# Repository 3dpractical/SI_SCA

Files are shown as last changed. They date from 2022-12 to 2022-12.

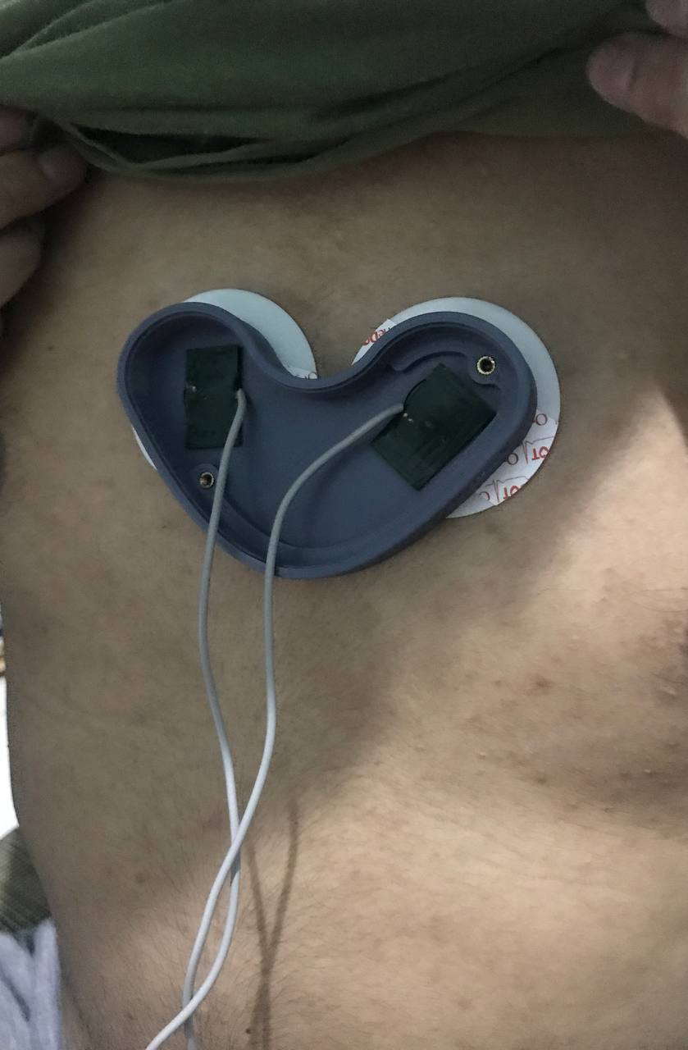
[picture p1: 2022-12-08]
Result Documentation/Pos-attempt01.jpg

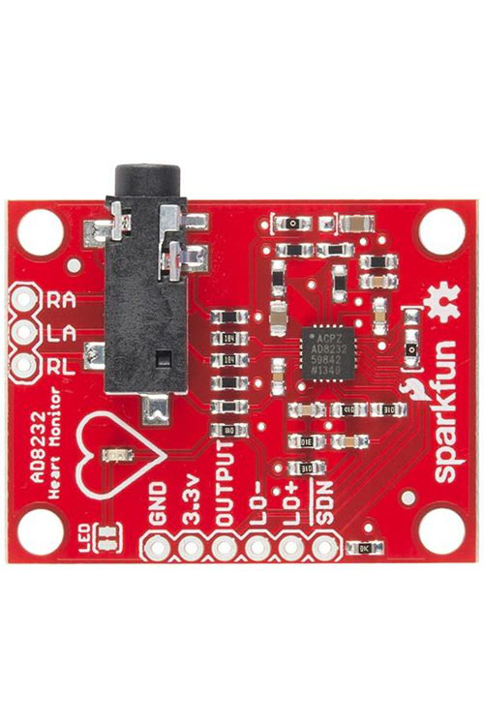
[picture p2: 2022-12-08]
Resources/REFERENCES/AD8232-ECG-Module.jpg

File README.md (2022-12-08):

# SI_SCA - Documentation





Si-SCA is a project to monitor heart rate and gyro status using Bluetooth Low Energy devices based on ESP32. This repository contain firmware for the devices to be installed.

## Library Used

 - [Adafruit MPU 6050](https://github.com/adafruit/Adafruit_MPU6050)
 - [NimBLE](https://github.com/h2zero/esp-nimble-cpp)
 - [RGB LED](https://github.com/FastLED/FastLED)
 - [FreeRTOS](https://docs.espressif.com/projects/esp-idf/en/latest/esp32/api-reference/system/freertos.html)
 - [TaskScheduler](https://github.com/arkhipenko/TaskScheduler)

## To-Do-List

- [X] ~~Establish Bluetooth Connection~~
- [X] ~~AD8232 HR Sensor Research~~
- [X] ~~Validate and Calibrate HR data~~
- [X] ~~MPU6050 get fixed Gyro data~~
- [X] ~~Validate and Calibrate Gyro data~~
- [X] ~~Get Battery Percentage Level~~
- [X] ~~Update BLE using NimBLE~~
- [X] ~~Add RGB Indicator~~
- [X] ~~Add Buzzer Indicator~~
- [X] ~~Configure Sleep Mode~~
- [X] ~~Import RTOS for better timing management~~
- [ ] Add AI for ECG signal detector

## License
This project is licensed under the MIT License - see the [LICENSE.md](LICENSE) file for details.

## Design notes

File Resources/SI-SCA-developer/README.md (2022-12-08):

# si_sca

A new Flutter project.

## Getting Started

This project is a starting point for a Flutter application.

A few resources to get you started if this is your first Flutter project:

- [Lab: Write your first Flutter app](https://flutter.dev/docs/get-started/codelab)
- [Cookbook: Useful Flutter samples](https://flutter.dev/docs/cookbook)

For help getting started with Flutter, view our
[online documentation](https://flutter.dev/docs), which offers tutorials,
samples, guidance on mobile development, and a full API reference.

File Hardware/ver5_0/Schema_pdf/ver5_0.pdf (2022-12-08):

# GND ¹k

Sheet: ABCD | 1 | 2 | 3 | 4 | 5 | 6 | ABCD 1 | 2 | 3 | 4 | 5 | 6

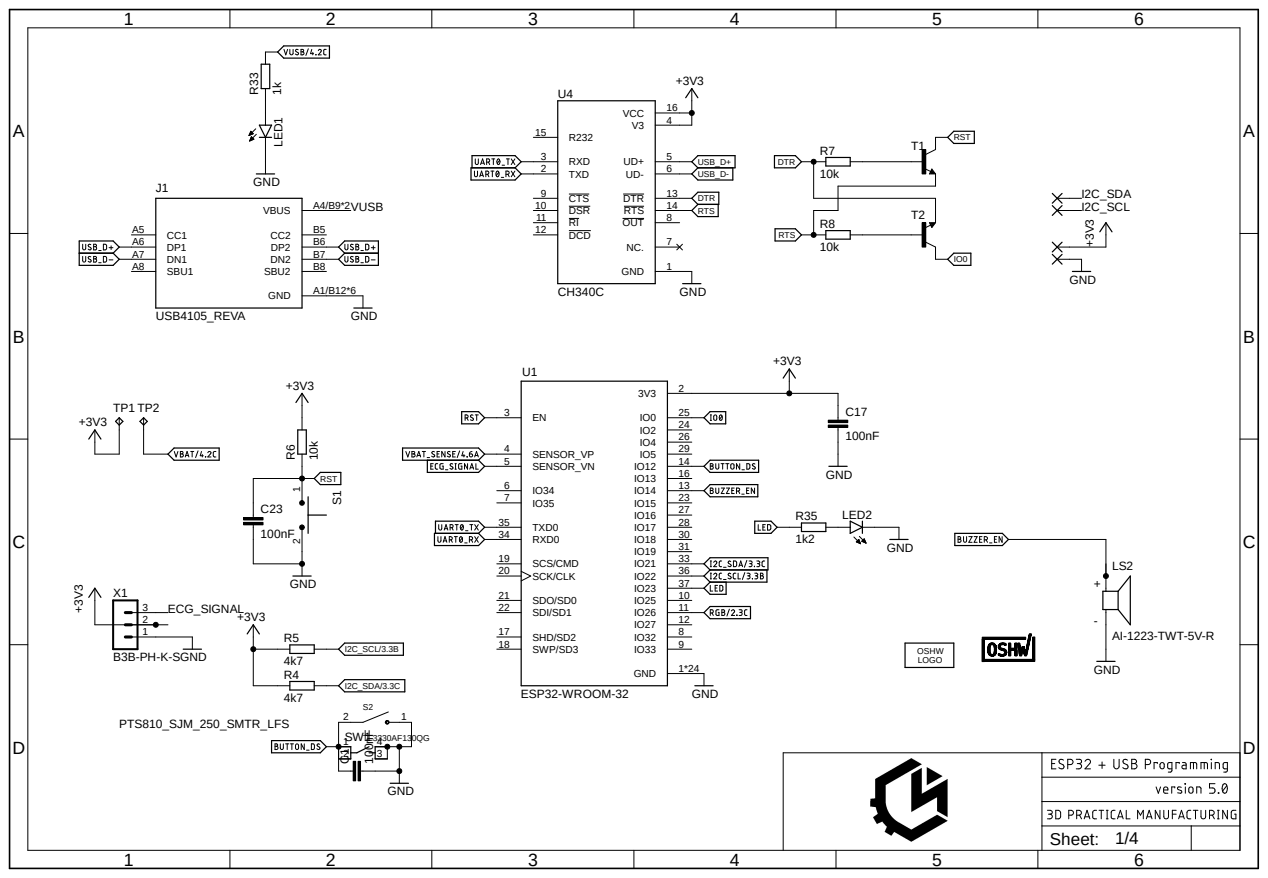
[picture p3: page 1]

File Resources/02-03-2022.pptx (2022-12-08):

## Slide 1

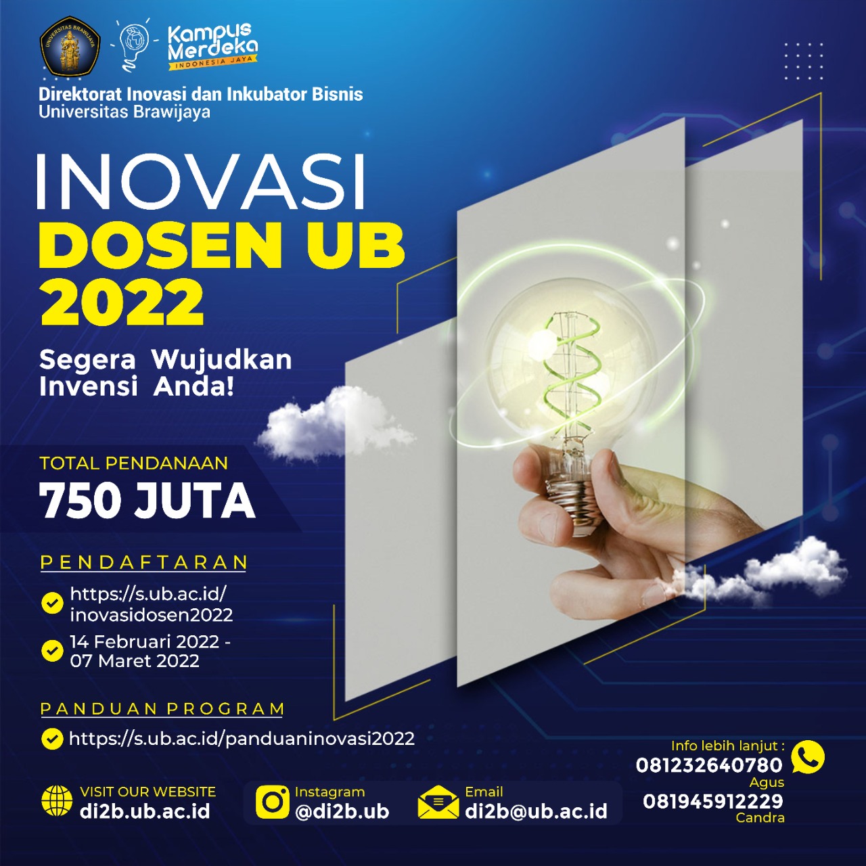
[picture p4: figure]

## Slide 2

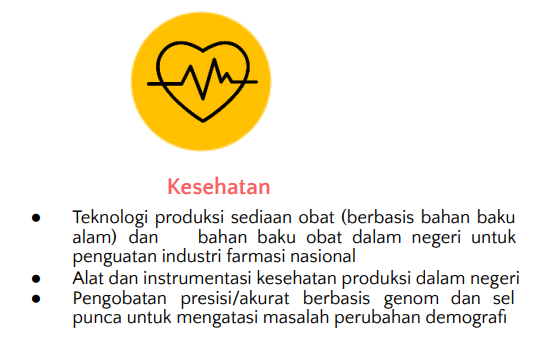
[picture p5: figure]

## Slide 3

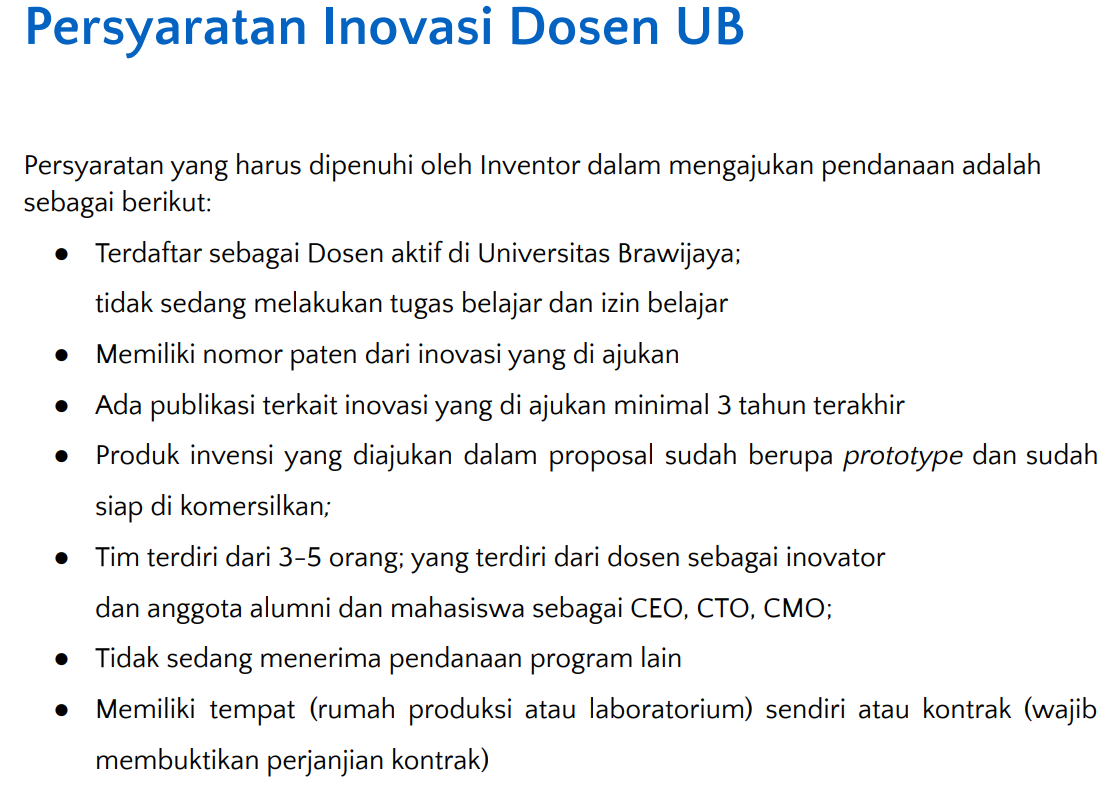
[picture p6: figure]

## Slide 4

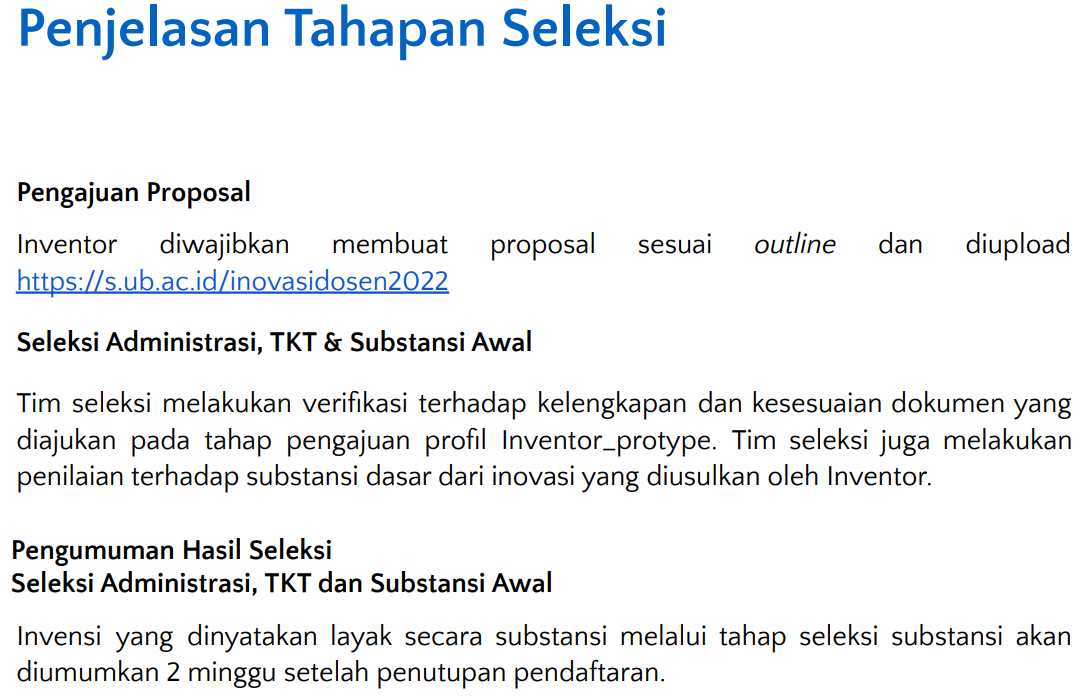
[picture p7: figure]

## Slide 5

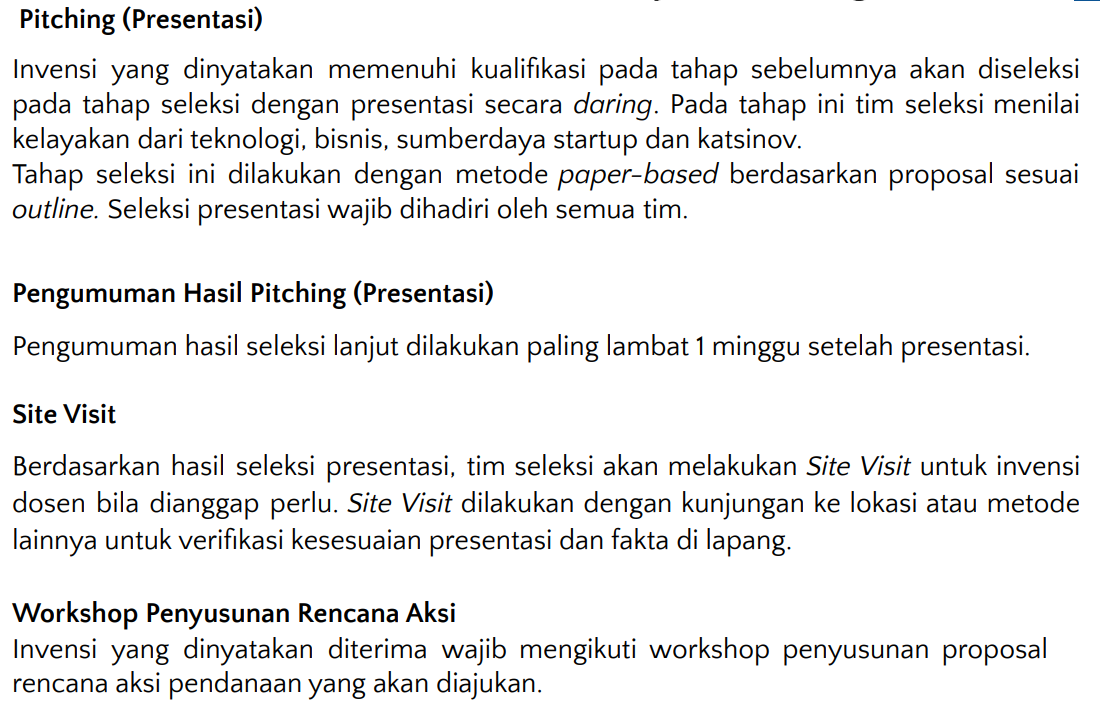
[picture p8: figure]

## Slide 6

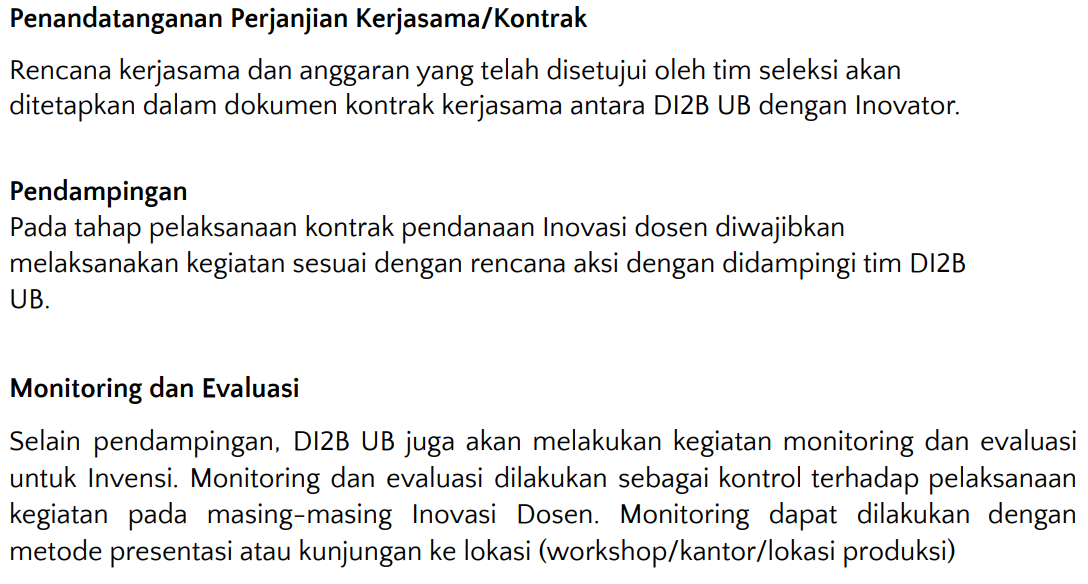
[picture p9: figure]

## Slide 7

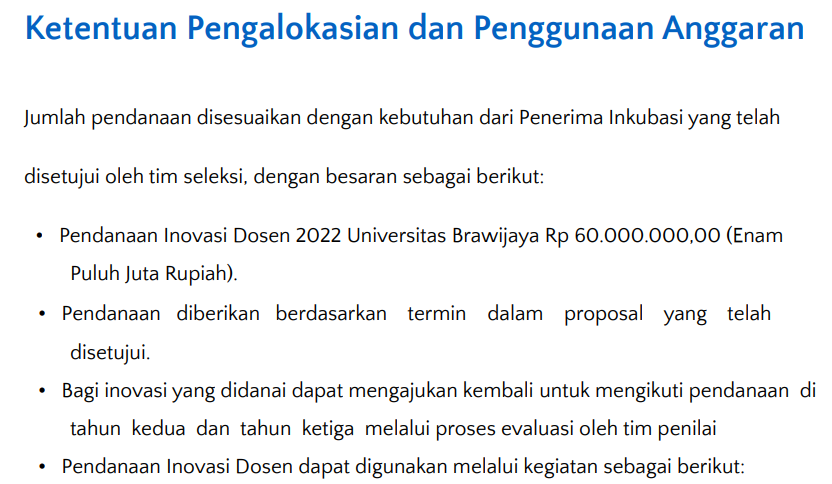
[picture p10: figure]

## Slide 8

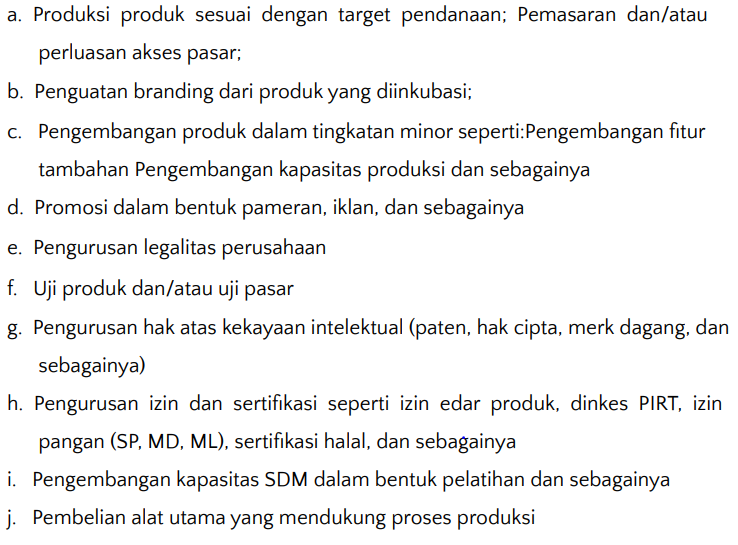
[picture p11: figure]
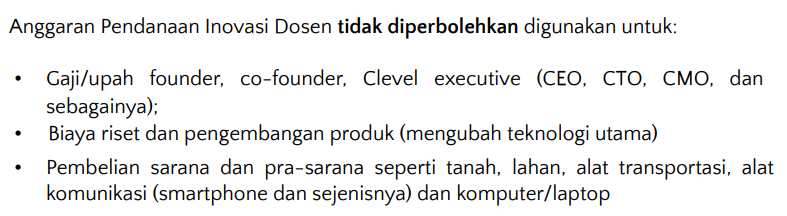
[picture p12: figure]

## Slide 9

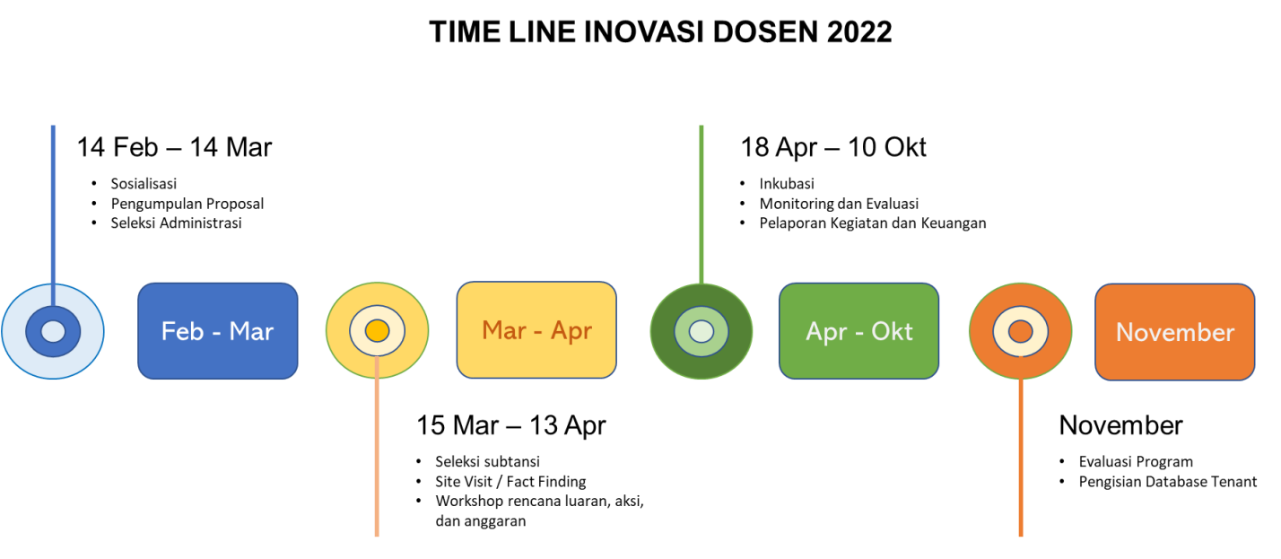
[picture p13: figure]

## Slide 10

Cover – Agil
Ringkasan Eksekutif – Agil
Lempeng – Agil
Profil Tim dan desain proposal – Agil
Bab 1 - Anita
Bab 2 – Chandra
Bab 3 - Chandra, Adrian, Rosa
Bab 4 - Rosa
Bab 5 - Chandra, Adrian, Rosa
Bab 6 - Chandra, Adrian, Rosa
Bab 7 - Chandra, Adrian, Rosa
Deadline 10 Maret + meeting lagi (jam menyusul)
13 Maret Dikumpul

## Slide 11

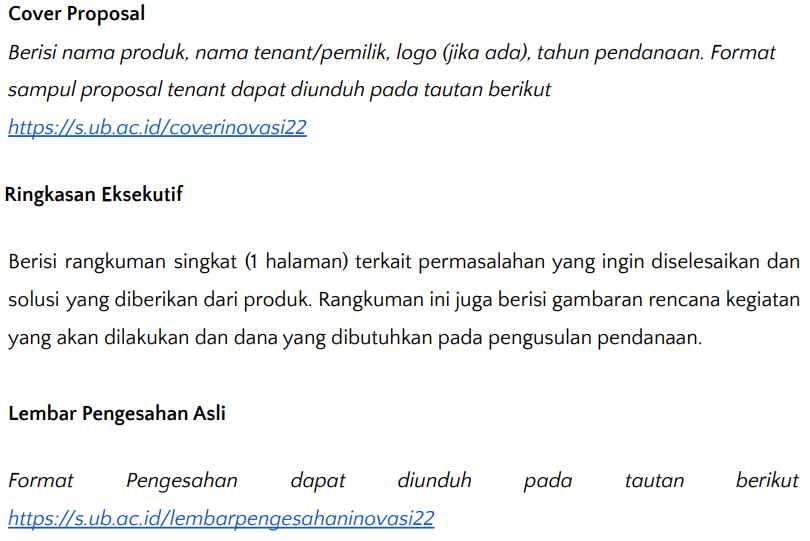
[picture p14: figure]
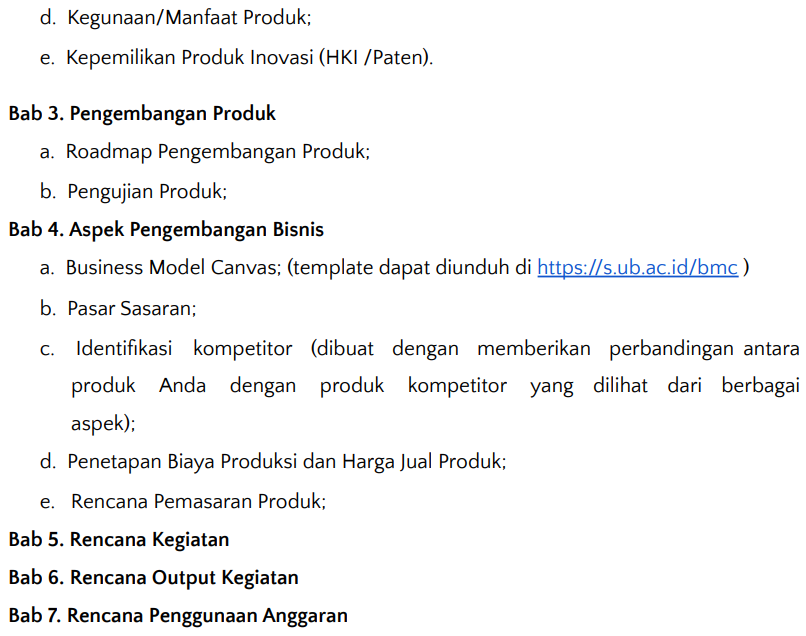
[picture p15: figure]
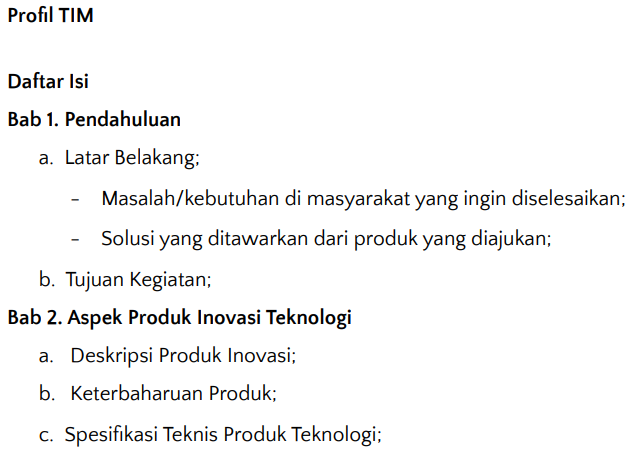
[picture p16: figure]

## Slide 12

Smart Wearable ECG EKG Monitor - (https://www.qardio.com/qardiocore-wearable-ecg-ekg-monitor-iphone/)QardioCore (https://www.qardio.com/qardiocore-wearable-ecg-ekg-monitor-iphone/)

HEALTHCARE PROFESSIONALS - (https://www.preventicesolutions.com/healthcare-professionals/)Preventice (https://www.preventicesolutions.com/healthcare-professionals/) Solutions (https://www.preventicesolutions.com/healthcare-professionals/)

EKG Anywhere, Anytime | (https://www.kardia.com/)AliveCor (https://www.kardia.com/) (kardia.com)

WISH for Health on Instagram: “Halo (https://www.instagram.com/p/CU9FhnEBYKi/?utm_source=ig_web_copy_link)teman-teman (https://www.instagram.com/p/CU9FhnEBYKi/?utm_source=ig_web_copy_link) (https://www.instagram.com/p/CU9FhnEBYKi/?utm_source=ig_web_copy_link)Imersif (https://www.instagram.com/p/CU9FhnEBYKi/?utm_source=ig_web_copy_link) Mari (https://www.instagram.com/p/CU9FhnEBYKi/?utm_source=ig_web_copy_link)kita (https://www.instagram.com/p/CU9FhnEBYKi/?utm_source=ig_web_copy_link) (https://www.instagram.com/p/CU9FhnEBYKi/?utm_source=ig_web_copy_link)sambut (https://www.instagram.com/p/CU9FhnEBYKi/?utm_source=ig_web_copy_link) (https://www.instagram.com/p/CU9FhnEBYKi/?utm_source=ig_web_copy_link)awal (https://www.instagram.com/p/CU9FhnEBYKi/?utm_source=ig_web_copy_link) (https://www.instagram.com/p/CU9FhnEBYKi/?utm_source=ig_web_copy_link)bulan (https://www.instagram.com/p/CU9FhnEBYKi/?utm_source=ig_web_copy_link) (https://www.instagram.com/p/CU9FhnEBYKi/?utm_source=ig_web_copy_link)dengan (https://www.instagram.com/p/CU9FhnEBYKi/?utm_source=ig_web_copy_link) quiz (https://www.instagram.com/p/CU9FhnEBYKi/?utm_source=ig_web_copy_link)menarik (https://www.instagram.com/p/CU9FhnEBYKi/?utm_source=ig_web_copy_link) (https://www.instagram.com/p/CU9FhnEBYKi/?utm_source=ig_web_copy_link)dari (https://www.instagram.com/p/CU9FhnEBYKi/?utm_source=ig_web_copy_link) WISH Buat kalian followers (https://www.instagram.com/p/CU9FhnEBYKi/?utm_source=ig_web_copy_link)kita (https://www.instagram.com/p/CU9FhnEBYKi/?utm_source=ig_web_copy_link) (https://www.instagram.com/p/CU9FhnEBYKi/?utm_source=ig_web_copy_link)pasti (https://www.instagram.com/p/CU9FhnEBYKi/?utm_source=ig_web_copy_link) tau (https://www.instagram.com/p/CU9FhnEBYKi/?utm_source=ig_web_copy_link)apa (https://www.instagram.com/p/CU9FhnEBYKi/?utm_source=ig_web_copy_link) (https://www.instagram.com/p/CU9FhnEBYKi/?utm_source=ig_web_copy_link)saja (https://www.instagram.com/p/CU9FhnEBYKi/?utm_source=ig_web_copy_link) (https://www.instagram.com/p/CU9FhnEBYKi/?utm_source=ig_web_copy_link)fitur (https://www.instagram.com/p/CU9FhnEBYKi/?utm_source=ig_web_copy_link) yang…” (https://www.instagram.com/p/CU9FhnEBYKi/?utm_source=ig_web_copy_link)

Spire Health | Remote Patient Monitoring (https://www.spirehealth.com/)

Aktiia (https://aktiia.com/uk/) - Your Home Blood Pressure Monitoring Solution (https://aktiia.com/uk/)

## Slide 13

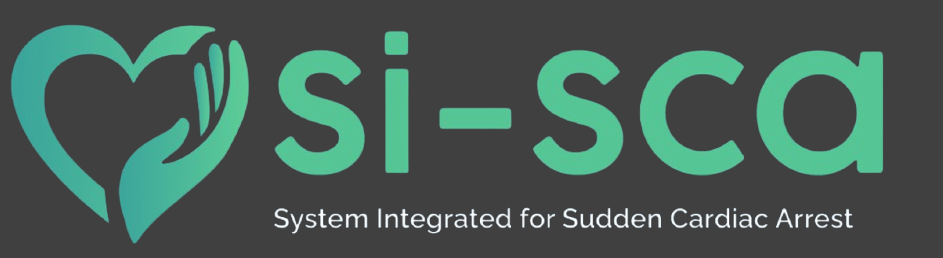
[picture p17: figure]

2.0 ?

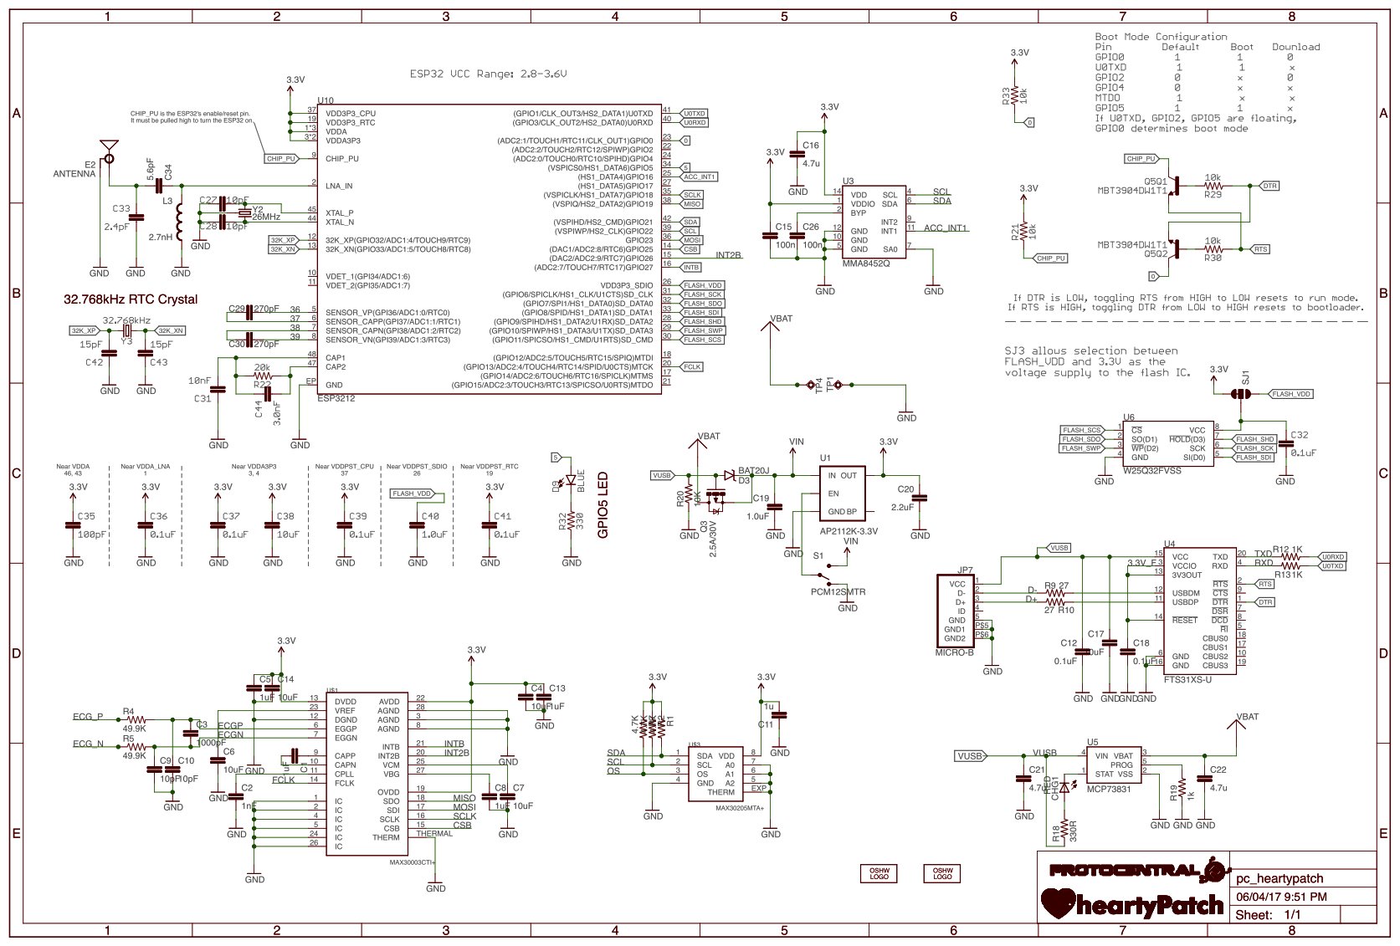
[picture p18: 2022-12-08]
Resources/Protocentral PCB Schematic.jpg

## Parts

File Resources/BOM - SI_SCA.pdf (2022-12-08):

No. | Item | Qty | Price Total
1 | Hardware Development | 1 | Rp10,000,000.00
2 | Programming | 1 | Rp4,000,000.00
3 | BLE Configuration | 1 | Rp1,500,000.00
4 | Backend App | 1 | Rp6,000,000.00
5 | Frontend App | 1 | Rp5,000,000.00
6 | AI Detection Method | 1 | Rp7,000,000.00
TOTAL | | | Rp33,500,000.00

Bill Of Material
SISCAA - EKG BPM Monitoring

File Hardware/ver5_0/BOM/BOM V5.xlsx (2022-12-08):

Qty | Value | Device | Package | Parts | Description | AVAILABILITY | DESCRIPTION | MF | MP | PACKAGE | POPULARITY | PRICE | PURCHASE-URL | SPICEPREFIX | TP_SIGNAL_NAME
1 |  | CERT-SMALL | CERT-SMALL-SILK | U$10
4 |  | LEDCHIP-LED0603 | CHIP-LED0603 | LED1, LED2, LED3, LED4 | LED |  |  |  |  |  | 26
2 |  | MMBT4401LT1-NPN-SOT23-BEC | SOT23-BEC | T1, T2 | NPN Transistror
1 | 100 | R-EU_R0603 | R0603 | R13 | RESISTOR, European symbol |  |  |  |  |  | 70 |  |  | R
1 | 100k | R-EU_R0603 | R0603 | R15 | RESISTOR, European symbol |  |  |  |  |  | 70 |  |  | R
8 | 100nF | C-EUC0603 | C0603 | C1, C4, C17, C23, C24, C29, C31, C32 | CAPACITOR, European symbol |  |  |  |  |  | 73 |  |  | C
5 | 10k | R-EU_R0603 | R0603 | R6, R7, R8, R9, R16 | RESISTOR, European symbol |  |  |  |  |  | 70 |  |  | R
1 | 10uF | C-EUC0603 | C0603 | C5 | CAPACITOR, European symbol |  |  |  |  |  | 73 |  |  | C
1 | 1N5819HW-7 | 1N5819HW-7 | SOD3715X145N | D2 | 1N5819HW Series 40 V 1 A Surface Mount Schottky Barrier Rectifier - SOD-123 Check availability | In Stock | Diode Schottky 40 V 1A Surface Mount SOD-123 | Diodes Inc. | 1N5819HW-7 | SOD-123 Fairchild Semiconductor |  | None | https://pricing.snapeda.com/search/part/1N5819HW-7/?ref=eda
4 | 1k | R-EU_R0603 | R0603 | R1, R2, R12, R33 | RESISTOR, European symbol |  |  |  |  |  | 70 |  |  | R
2 | 1k2 | R-EU_R0603 | R0603 | R3, R35 | RESISTOR, European symbol |  |  |  |  |  | 70 |  |  | R
2 | 1uF | C-EUC0603 | C0603 | C6, C7 | CAPACITOR, European symbol |  |  |  |  |  | 73 |  |  | C
1 | 220pF | C-EUC0603 | C0603 | C30 | CAPACITOR, European symbol |  |  |  |  |  | 73 |  |  | C
1 | 27k | R-EU_R0603 | R0603 | R14 | RESISTOR, European symbol |  |  |  |  |  | 70 |  |  | R
4 | 4k7 | R-EU_R0603 | R0603 | R4, R5, R10, R11 | RESISTOR, European symbol |  |  |  |  |  | 70 |  |  | R
1 | AI-1223-TWT-5V-R | AI-1223-TWT-5V-R | XDCR_AI-1223-TWT-5V-R | LS2 | Check availability | In Stock | ELECTRO MECHANICAL AUDIO INDICATOR | PUI Audio, | AI-1223-TWT-5V-R | 2225 PUI Audio |  | None | https://pricing.snapeda.com/search/part/AI-1223-TWT-5V-R/?ref=eda
1 | B3B-PH-K-S | B3B-PH-K-S | B3B-PH-K-S | X1 | JST PH series header 2.00mm pitch disconnectable crimp style connectors, vertical (side entry type), 3 pins
1 | CH340C | CH340C | SOIC127P600X180-16N | U4 | USB to serial chip CH340 Check availability | Not in stock | USB to serial chip CH340 | WCH | CH340C | None |  | None
1 | DW01A | DW01A | SOT23-6 | IC2 | Check availability | Not in stock | One Cell Lithium-ion/Polymer Battery Protection IC | Fortune Semiconductor | DW01A | SOT-23-6 Fortune Semiconductor |  | None
1 | ESP32-WROOM-32 | ESP32-WROOM-32 | MODULE_ESP32-WROOM-32 | U1 | Bluetooth, WiFi Transceiver Module 2.4GHz ~ 2.5GHz Surface Mount | Unavailable | Bluetooth, WiFi 802.11b/g/n, Bluetooth v4.2 +EDR, Class 1, 2 and 3 Transceiver Module 2.4GHz ~ 2.5GHz Antenna Not Included, U.FL Surface Mount | Espressif Systems | ESP32-WROOM-32 | Module Espressif Systems |  | None
1 | FS8205A | FS8205A | SOP65P640X120-8N | Q3 | N/A Check availability | Not in stock |  | Fortune Semiconductor | FS8205A | Package |  | None
1 | MCP1700T-3302E/TT | MCP1700T-3302E/TT | SOT95P237X112-3N | U$2 | Check availability | In Stock | Linear Voltage Regulator IC Positive Fixed 1 Output 250mA SOT-23-3 | Microchip | MCP1700T-3302E/TT | SOT-23 Microchip |  | None | https://pricing.snapeda.com/search/part/MCP1700T-3302E/TT/?ref=eda
1 | MPU-6050 | MPU-6050 | QFN50P400X400X95-24N | U11 | MPU-6050 Six-Axis (Gyro + Accelerometer) MEMS MotionTracking™ Devices Check availability | In Stock | MPU-6050 series Accelerometer, Gyroscope, 3 Axis Sensor Evaluation Board | TDK InvenSense | MPU-6050 | QFN-24 InvenSense |  | None | https://pricing.snapeda.com/search/part/MPU-6050/?ref=eda
1 | OSHW_LOGO_FILLX0200-NT | OSHW_LOGO_FILLX0200-NT | OSHW_FILLX200_NOTEXT | LOGO2
1 | PTS810_SJM_250_SMTR_LFS | PTS810_SJM_250_SMTR_LFS | SW_PTS810_SJM_250_SMTR_LFS | SW1 | Switch Tactile Spst-No 0.05a 16v Check prices | In Stock | Tactile Switch SPST-NO Top Actuated Surface Mount | C&K | PTS810 SJM 250 SMTR LFS | None |  | None | https://pricing.snapeda.com/search/part/PTS810 SJM 250 SMTR LFS/?ref=eda
1 | TL1015AF160QG | TL1015AF160QG | SW_TL1015AF160QG | S1 | Tactile Switch SPST-NO Top Actuated Surface Mount Check prices | In Stock | Tactile Switch SPST-NO Top Actuated Surface Mount | E-Switch | TL1015AF160QG | SOIC-14 E-Switch |  | None | https://pricing.snapeda.com/search/part/TL1015AF160QG/?ref=eda
1 | TL3330AF130QG | TL3330AF130QG | SW_TL3330AF130QG | S2 | Check availability | In Stock | Tactile Switch SPST-NO Side Actuated Surface Mount, Right Angle | E-Switch | TL3330AF130QG | None |  | None | https://pricing.snapeda.com/search/part/TL3330AF130QG/?ref=eda
1 | TP4056 | TP4056 | SOP127P600X175-9N | U2 | Complete single cell Li-Ion battery with a constant current / constant voltage linear charger Check availability | Not in stock | Complete single cell Li-Ion battery with a constant current / constant voltage linear charger | NanJing Top Power ASIC Corp. | TP4056 | None |  | None
2 | TPB1,27 | TPB1,27 | B1,27 | TP1, TP2 | Test pad |  |  |  |  |  | 19
1 | TRANSISTOR-FET_DMP2004K | TRANSISTOR-FET_DMP2004K | TRANSISTOR-FET_SOT23 | Q4 | P-Channel Enhancement MOSFET
1 | USB4105_REVA | USB4105_REVA | GCT_USB4105_REVA | J1 | USB Type C Receptacle for USB 2.0 | Unavailable | USB-C (USB TYPE-C) USB 2.0 Receptacle Connector 24 (16+8 Dummy) Position Surface Mount, Right Angle | Through Hole | Global Connector Technology | USB4105 | Package |  | None
6 | WIREPADSMD1,27-254 | WIREPADSMD1,27-254 | SMD1,27-2,54 | PAD1, PAD2, PAD3, PAD4, VBAT+, VBAT- | Wire PAD connect wire on PCB |  |  |  |  |  | 11
1 | WS2812B-B | WS2812B-B | LED_WS2812B-B | U5 | Intelligent control LED integrated light source Check availability | Not in stock | Intelligent control LED integrated light source | Worldsemi | WS2812B-B | Package |  | None

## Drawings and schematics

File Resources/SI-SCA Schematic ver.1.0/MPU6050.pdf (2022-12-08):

A

A

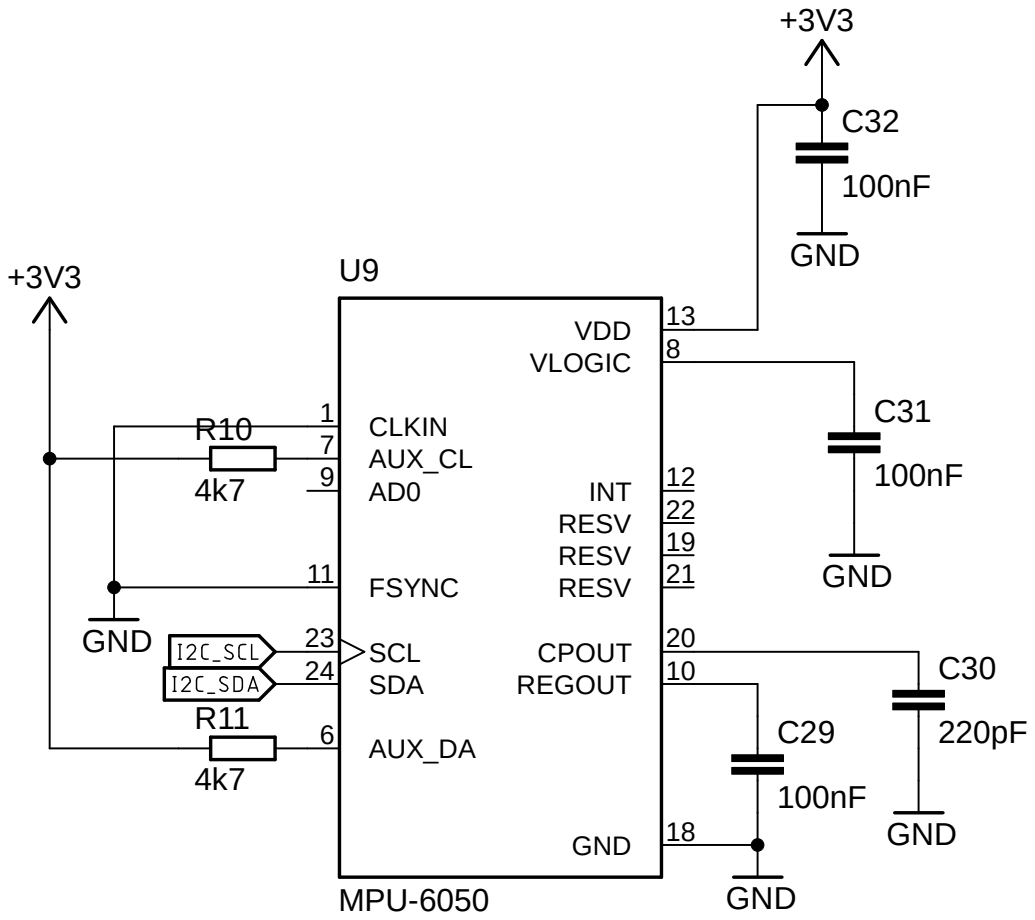
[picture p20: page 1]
GND; MPU-6050; GND +3V3; C31 CLKIN 1 AUX_CL 7 AD0 9; FSYNC 11; SCL 23; AUX_DA 6; SDA 24; INT; REGOUT; 10 CPOUT; RESV; VLOGIC; 8 VDD; Sheet:

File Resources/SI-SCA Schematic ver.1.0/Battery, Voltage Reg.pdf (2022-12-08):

A

A

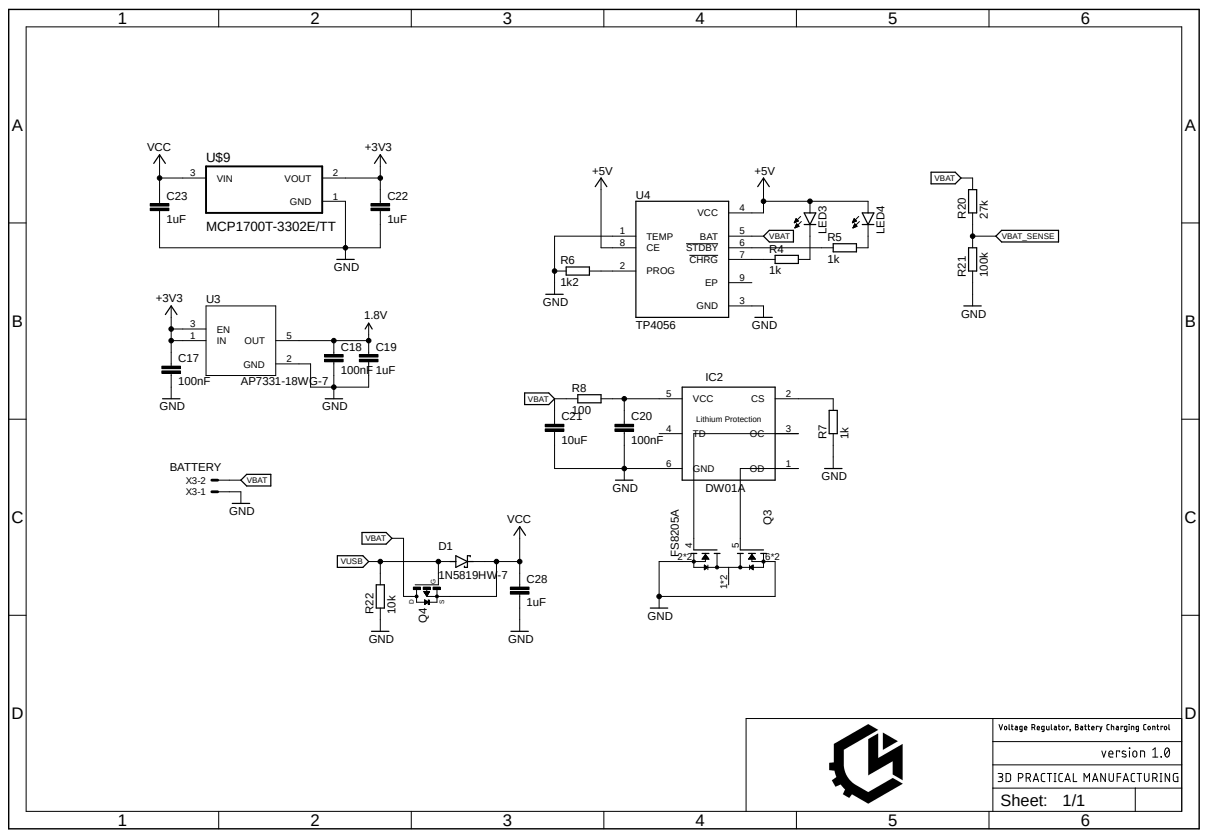
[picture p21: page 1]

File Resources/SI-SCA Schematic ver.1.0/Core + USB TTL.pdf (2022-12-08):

BUZZER | Sheet: ABCD | 1 | 2 | 3 | 4 | 5 | 6 | ABCD 1 | 2 | 3 | 4 | 5 | 6

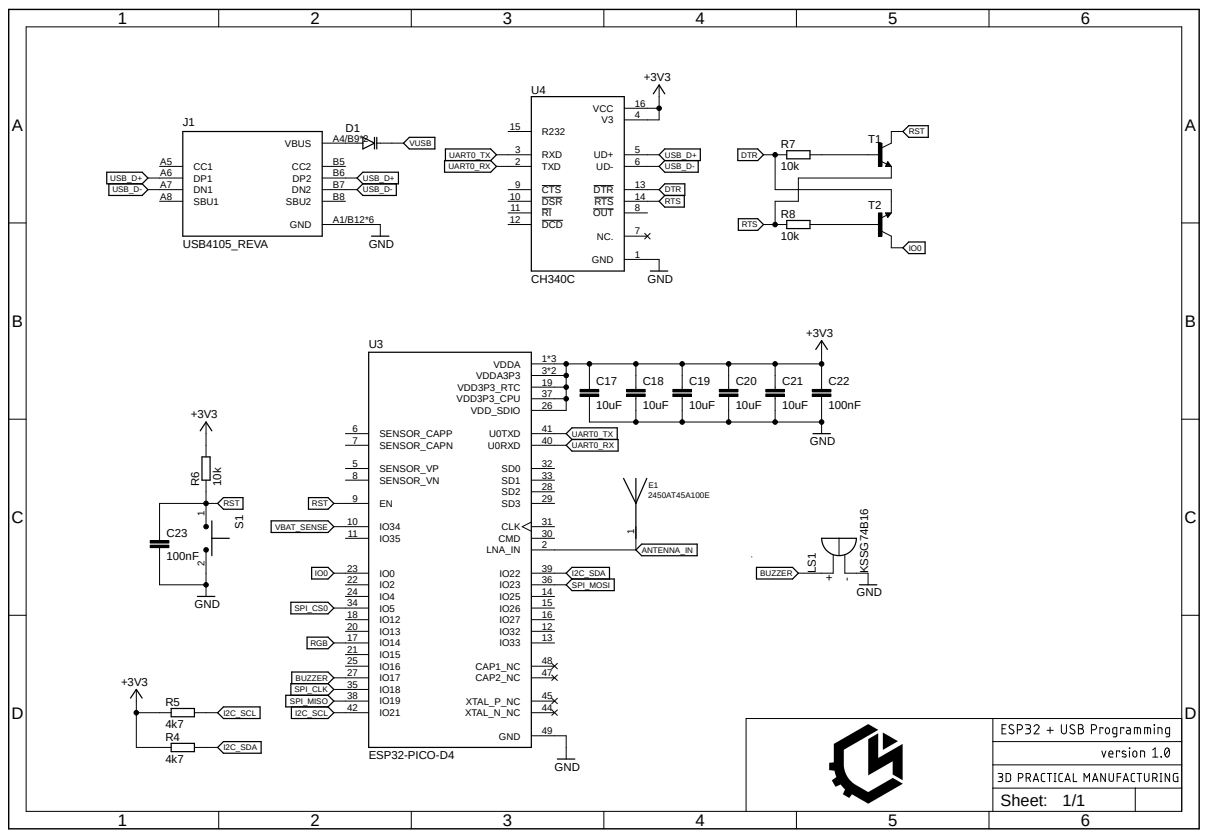
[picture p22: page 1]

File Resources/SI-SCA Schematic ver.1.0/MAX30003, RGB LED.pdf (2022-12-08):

A

A

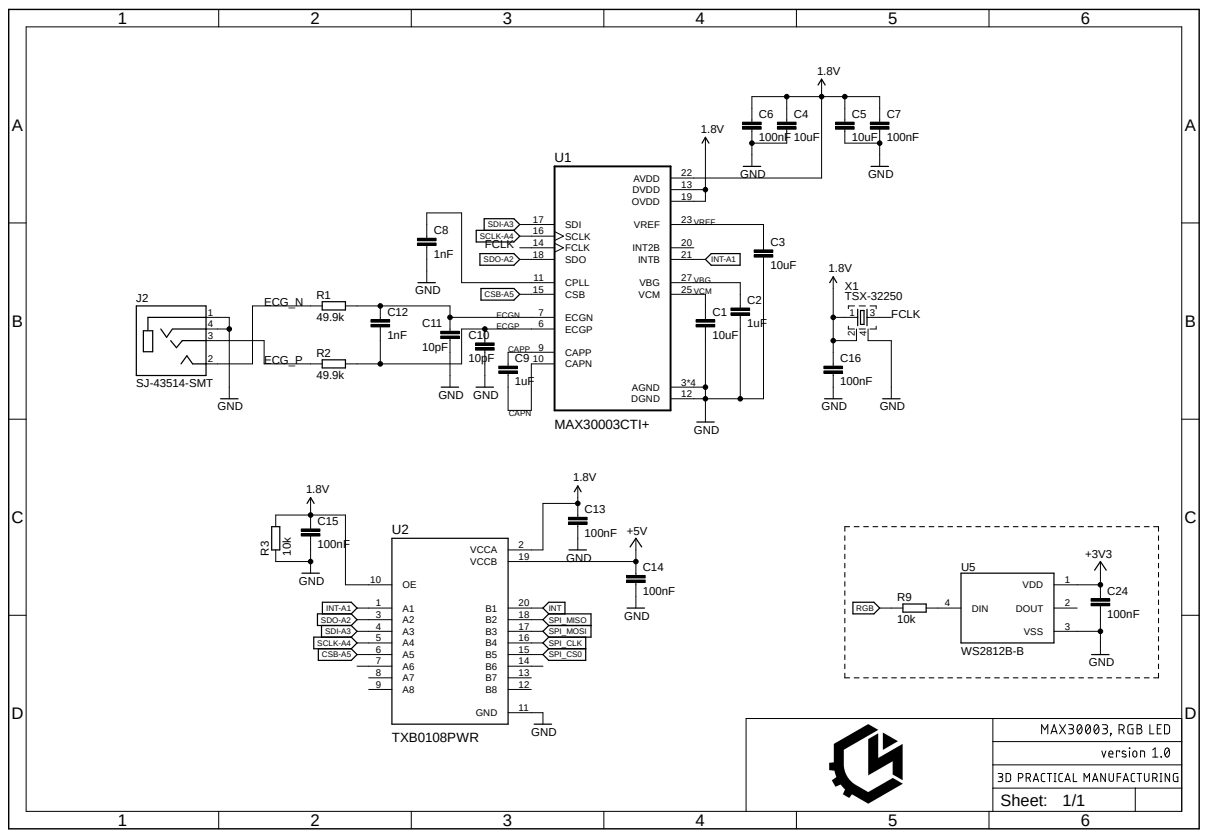
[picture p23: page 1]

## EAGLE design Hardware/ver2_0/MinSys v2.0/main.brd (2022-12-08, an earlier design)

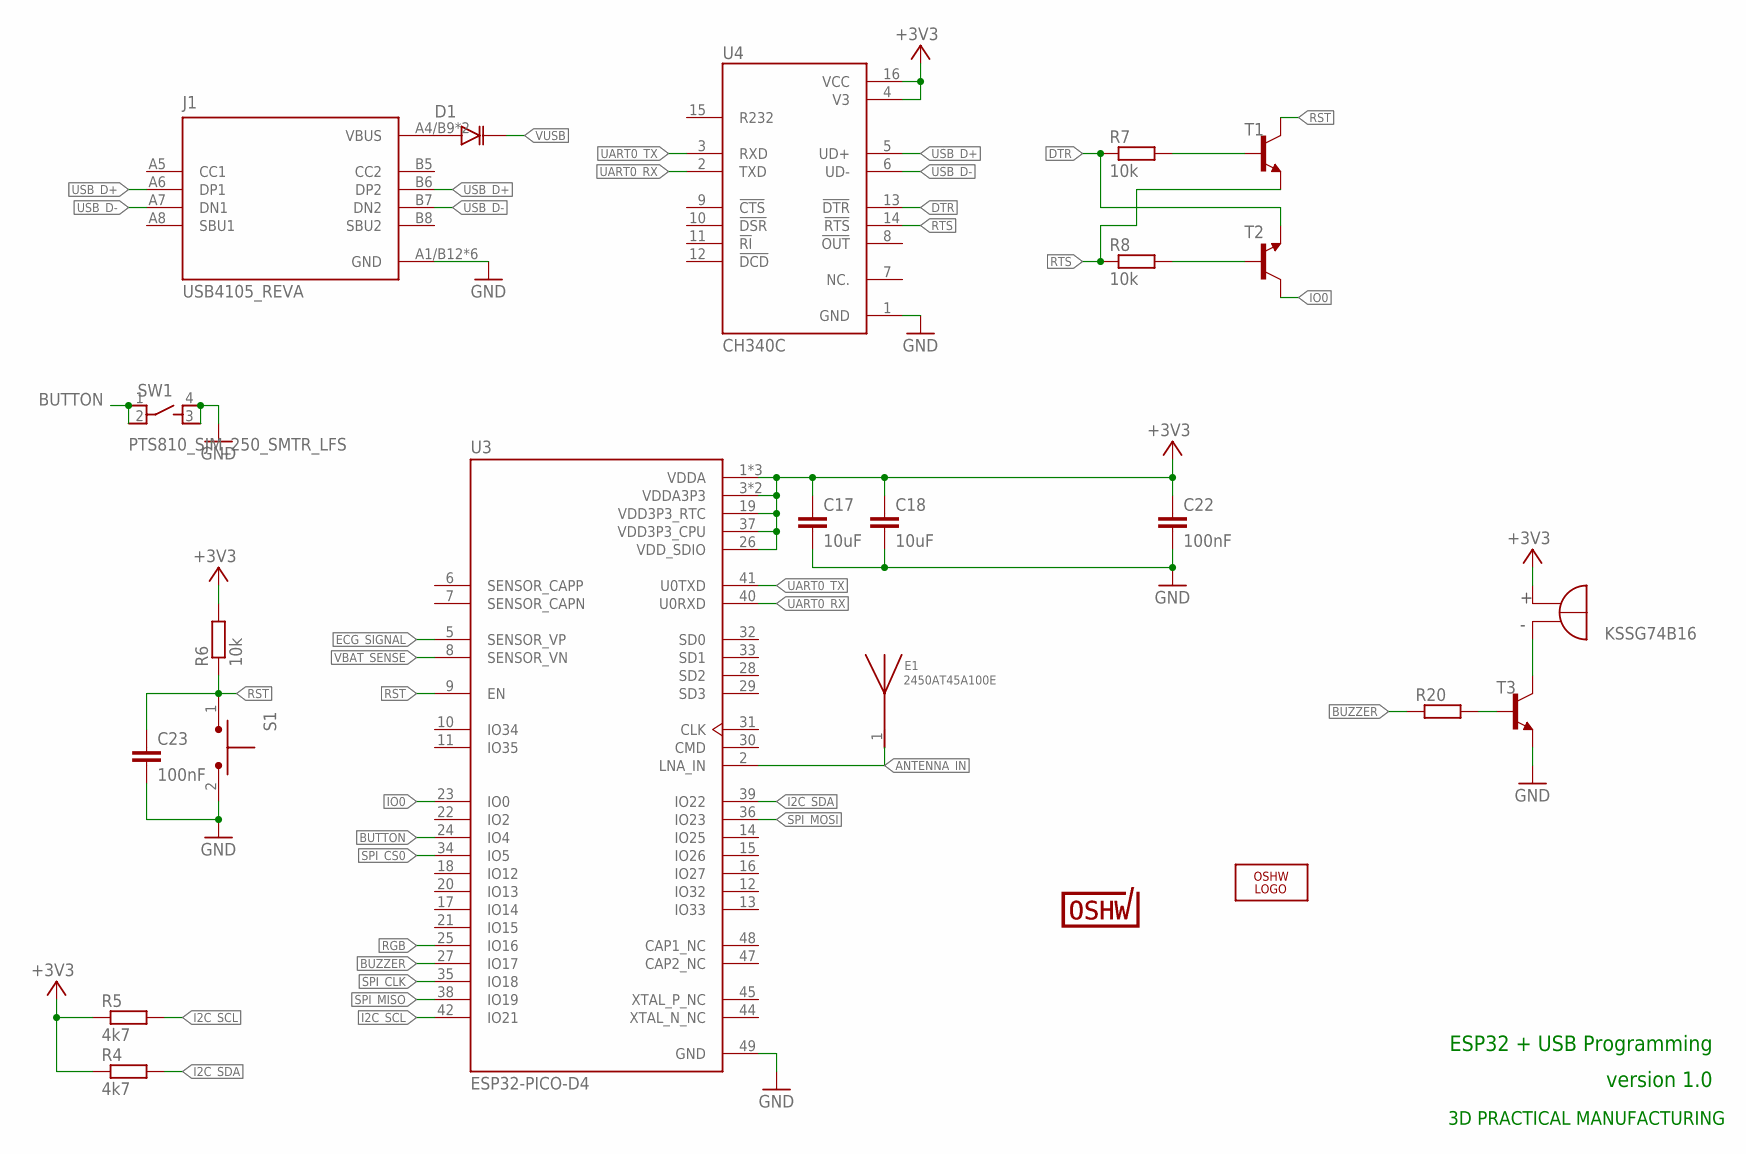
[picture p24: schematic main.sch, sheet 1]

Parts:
C17, C18: 10uF; C0603
C22, C23: 100nF; C0603
D1: ZMV829BTA; SOD2512X116N
E1: 2450AT45A100E; ANT_2450AT45A100E
J1: USB4105_REVA; GCT_USB4105_REVA
LOGO2: OSHW_LOGO_FILLX0200-NT; OSHW_FILLX200_NOTEXT
LS1: KSSG74B16; XDCR_KSSG74B16
R4, R5: 4k7; R0603
R6, R7, R8: 10k; R0603
R20: R-EU_R0603; R0603
S1: TL1015AF160QG; SW_TL1015AF160QG
SW1: PTS810_SJM_250_SMTR_LFS; SW_PTS810_SJM_250_SMTR_LFS
T1, T2, T3: MMBT4401LT1-NPN-SOT23-BEC; SOT23-BEC
U3: ESP32-PICO-D4; PQFN50P700X700X104-49N
U4: CH340C; SOIC127P600X180-16N
U$10: CERT-SMALL; CERT-SMALL-SILK

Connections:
+3V3: C17.1, C18.1, C22.1, LS1.P (POS), R4.1, R5.1, R6.2, U3.1 (VDDA), U3.3 (VDDA3P3), U3.4 (VDDA3P3), U3.19 (VDD3P3_RTC), U3.26 (VDD_SDIO), U3.37 (VDD3P3_CPU), U3.43 (VDDA), U3.46 (VDDA), U4.4 (V3), U4.16 (VCC); also elsewhere on the board
ANTENNA_IN: E1.1, U3.2 (LNA_IN)
BUTTON: SW1.1, SW1.2, U3.24 (IO4)
BUZZER: R20.1, U3.27 (IO17)
DTR: R7.1, T2.E, U4.13 (!DTR)
ECG_SIGNAL: U3.5 (SENSOR_VP); also elsewhere on the board
GND: C17.2, C18.2, C22.2, C23.2, J1.A1/B12 (GND), J1.B1/A12 (GND), J1.G1 (GND), J1.G2 (GND), J1.G3 (GND), J1.G4 (GND), S1.2, SW1.3, SW1.4, T3.E, U3.49 (GND), U4.1 (GND); also elsewhere on the board
I2C_SCL: R5.2, U3.42 (IO21); also elsewhere on the board
I2C_SDA: R4.2, U3.39 (IO22); also elsewhere on the board
IO0: T2.C, U3.23 (IO0)
unnamed: R7.2, T1.B
unnamed: R8.2, T2.B
unnamed: R20.2, T3.B
unnamed: D1.A, J1.A4/B9 (VBUS), J1.B4/A9 (VBUS)
unnamed: LS1.N (NEG), T3.C
RGB: U3.25 (IO16); also elsewhere on the board
RST: C23.1, R6.1, S1.1, T1.C, U3.9 (EN)
RTS: R8.1, T1.E, U4.14 (!RTS)
SPI_CLK: U3.35 (IO18)
SPI_CS0: U3.34 (IO5)
SPI_MISO: U3.38 (IO19)
SPI_MOSI: U3.36 (IO23)
UART0_RX: U3.40 (U0RXD), U4.2 (TXD)
UART0_TX: U3.41 (U0TXD), U4.3 (RXD)
USB_D+: J1.A6 (DP1), J1.B6 (DP2), U4.5 (UD+)
USB_D-: J1.A7 (DN1), J1.B7 (DN2), U4.6 (UD-)
VBAT_SENSE: U3.8 (SENSOR_VN); also elsewhere on the board
VUSB: D1.K; also elsewhere on the board

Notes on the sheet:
ESP32 + USB Programming
3D PRACTICAL MANUFACTURING
version 1.0

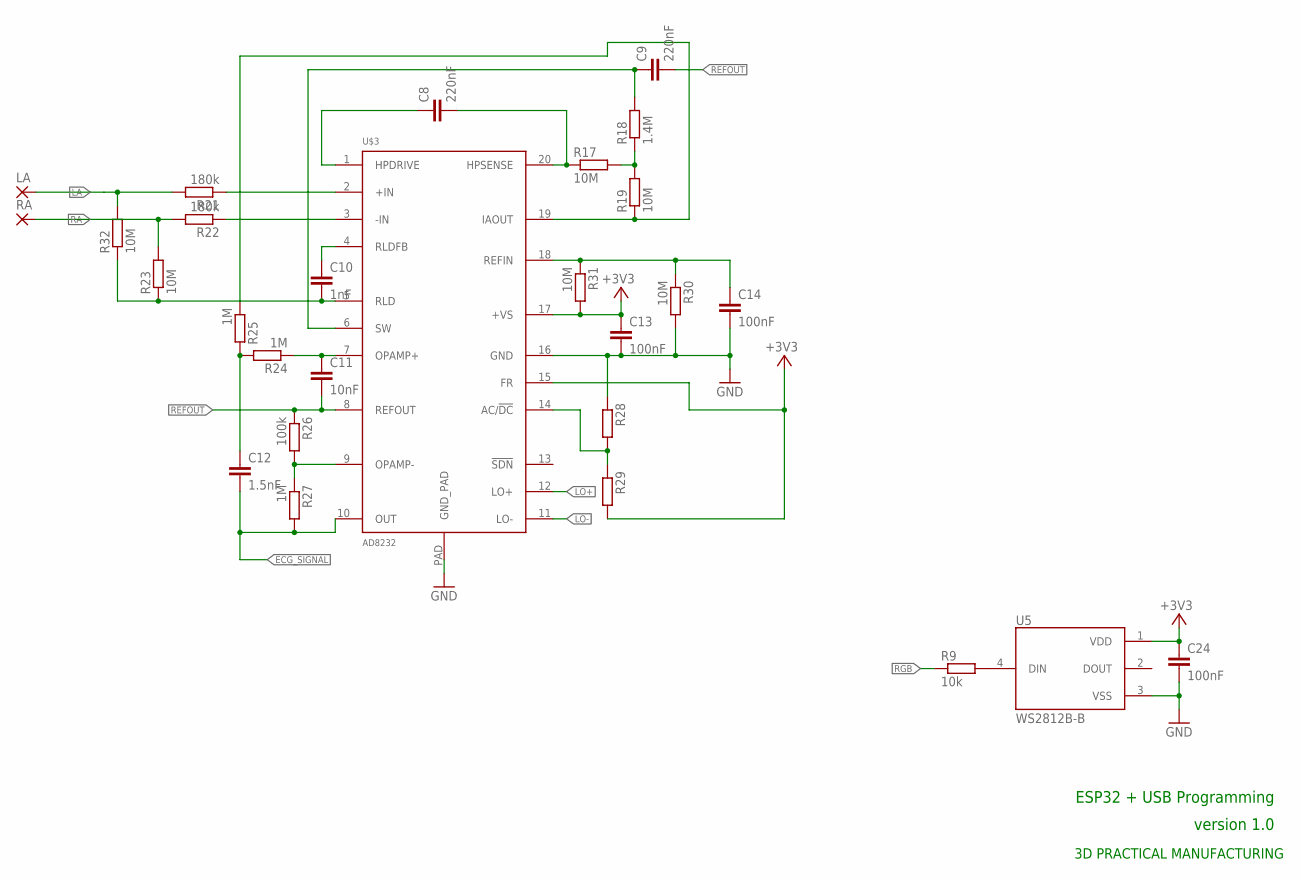
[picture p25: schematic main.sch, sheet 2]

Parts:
C8, C9: 220nF; C0603
C10: 1nF; C0603
C11: 10nF; C0603
C12: 1.5nF; C0603
C13, C14, C24: 100nF; C0603
LA: SMD2; SMD1,27-2,54
R9: 10k; R0603
R17, R19, R23, R30, R31, R32: 10M; R0603
R18: 1.4M; R0603
R21, R22: 180k; R0603
R24, R25, R27: 1M; R0603
R26: 100k; R0603
R28, R29: R-EU_R0603; R0603
RA: SMD2; SMD1,27-2,54
U5: WS2812B-B; LED_WS2812B-B
U$3: AD8232; LFCSP_20

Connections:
+3V3: C13.1, C24.1, R29.2, R31.2, U5.1 (VDD), U$3.15 (FR), U$3.17 (+VS); also elsewhere on the board
ECG_SIGNAL: C12.2, R27.2, U$3.10 (OUT); also elsewhere on the board
GND: C13.2, C14.2, C24.2, R28.1, R30.2, U5.3 (VSS), U$3.16 (GND), U$3.PAD (GND_PAD); also elsewhere on the board
LA: LA.1, R21.2, R32.2
LO+: U$3.12 (LO+)
LO-: U$3.11 (LO-)
unnamed: R9.2, U5.4 (DIN)
unnamed: C8.2, R17.1, U$3.20 (HPSENSE)
unnamed: C8.1, U$3.1 (HPDRIVE)
unnamed: R19.1, R25.1, U$3.19 (IAOUT)
unnamed: R17.2, R18.1, R19.2
unnamed: C9.1, R18.2, U$3.6 (SW)
unnamed: C12.1, R24.2, R25.2
unnamed: R21.1, U$3.2 (+IN)
unnamed: R22.1, U$3.3 (-IN)
unnamed: C10.1, U$3.4 (RLDFB)
unnamed: C10.2, R23.1, R32.1, U$3.5 (RLD)
unnamed: C11.1, R24.1, U$3.7 (OPAMP+)
unnamed: R26.2, R27.1, U$3.9 (OPAMP-)
unnamed: R28.2, R29.1, U$3.14 (AC/!DC)
unnamed: C14.1, R30.1, R31.1, U$3.18 (REFIN)
RA: R22.2, R23.2, RA.1
REFOUT: C9.2, C11.2, R26.1, U$3.8 (REFOUT)
RGB: R9.1; also elsewhere on the board

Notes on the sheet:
ESP32 + USB Programming
3D PRACTICAL MANUFACTURING
version 1.0

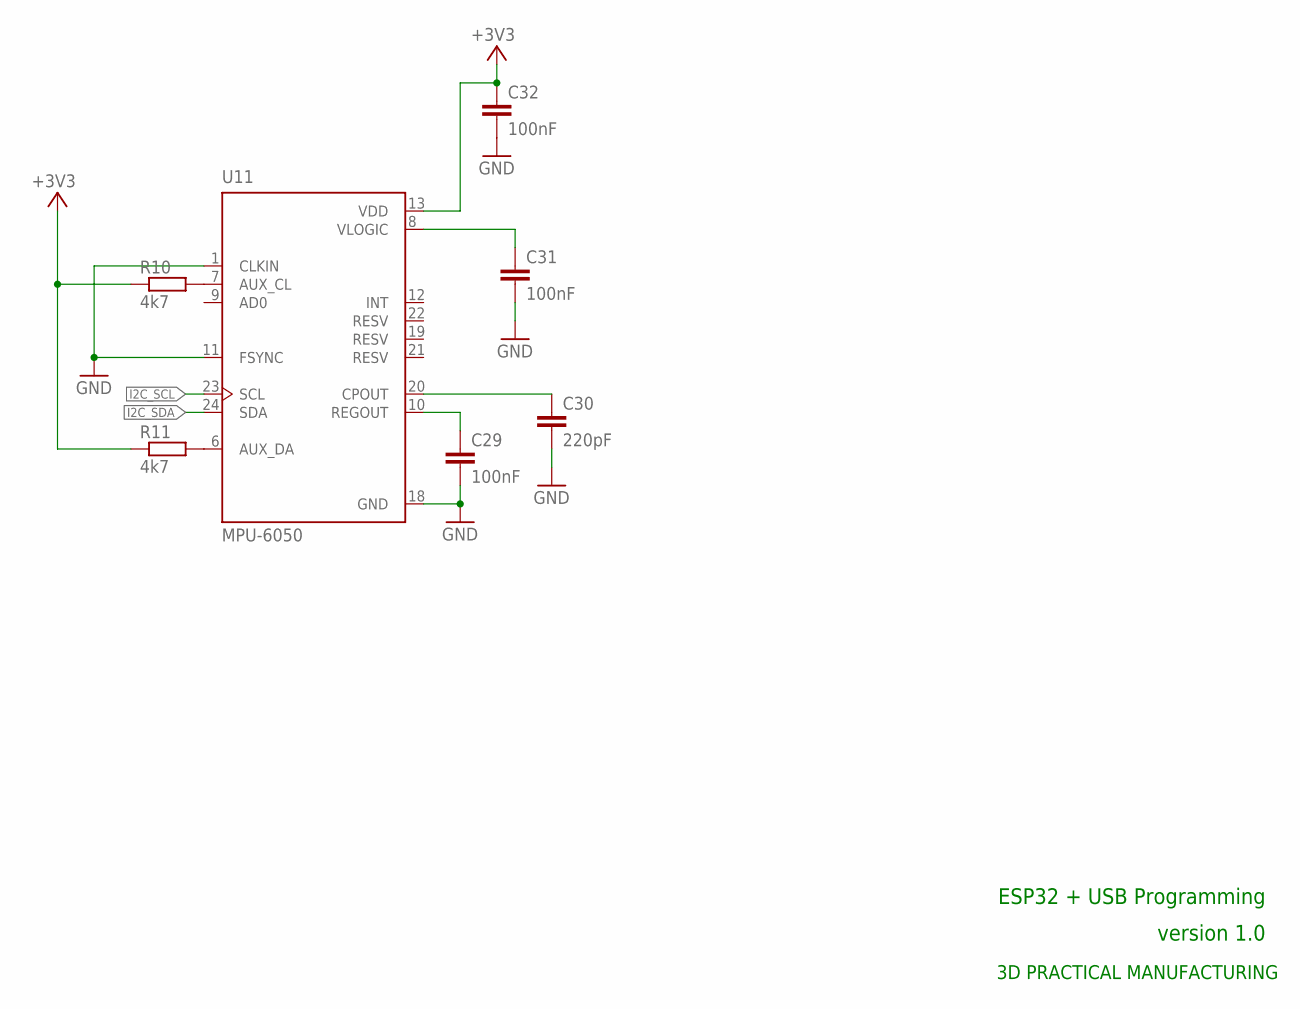
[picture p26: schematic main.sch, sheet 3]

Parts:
C29, C31, C32: 100nF; C0603
C30: 220pF; C0603
R10, R11: 4k7; R0603
U11: MPU-6050; QFN50P400X400X95-24N

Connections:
+3V3: C32.1, R10.1, R11.1, U11.13 (VDD); also elsewhere on the board
GND: C29.2, C30.2, C31.2, C32.2, U11.1 (CLKIN), U11.11 (FSYNC), U11.18 (GND); also elsewhere on the board
I2C_SCL: U11.23 (SCL); also elsewhere on the board
I2C_SDA: U11.24 (SDA); also elsewhere on the board
unnamed: C29.1, U11.10 (REGOUT)
unnamed: R10.2, U11.7 (AUX_CL)
unnamed: R11.2, U11.6 (AUX_DA)
unnamed: C31.1, U11.8 (VLOGIC)
unnamed: C30.1, U11.20 (CPOUT)

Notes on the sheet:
ESP32 + USB Programming
3D PRACTICAL MANUFACTURING
version 1.0

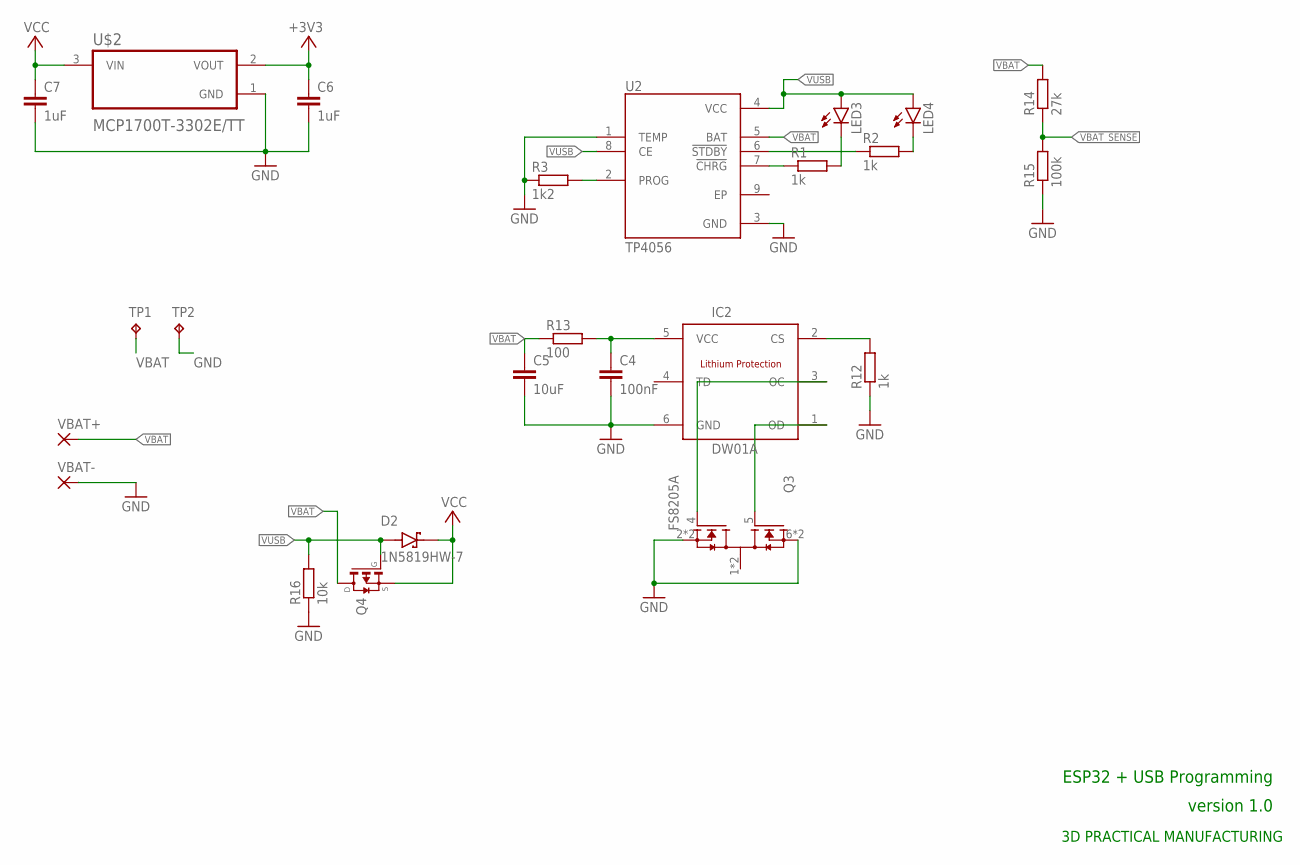
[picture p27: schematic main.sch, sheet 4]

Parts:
C4: 100nF; C0603
C5: 10uF; C0603
C6, C7: 1uF; C0603
D2: 1N5819HW-7; SOD3715X145N
IC2: DW01A; SOT23-6
LED3, LED4: LEDCHIP-LED0603; CHIP-LED0603
Q3: FS8205A; SOP65P640X120-8N
Q4: TRANSISTOR-FET_DMP2004K; TRANSISTOR-FET_SOT23
R1, R2, R12: 1k; R0603
R3: 1k2; R0603
R13: 100; R0603
R14: 27k; R0603
R15: 100k; R0603
R16: 10k; R0603
TP1, TP2: TPB1,27; B1,27
U2: TP4056; SOP127P600X175-9N
U$2: MCP1700T-3302E/TT; SOT95P237X112-3N
VBAT+: WIREPADSMD1,27-254; SMD1,27-2,54
VBAT-: WIREPADSMD1,27-254; SMD1,27-2,54

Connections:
+3V3: C6.1, U$2.2 (VOUT); also elsewhere on the board
GND: C4.2, C5.2, C6.2, C7.2, IC2.6 (GND), Q3.2 (S1), Q3.3 (S1), Q3.6 (S2), Q3.7 (S2), R3.1, R12.1, R15.1, R16.1, TP2.TP, U2.1 (TEMP), U2.3 (GND), U$2.1 (GND), VBAT-.1; also elsewhere on the board
unnamed: R2.1, U2.6 (!STDBY)
unnamed: LED3.C, R1.2
unnamed: LED4.C, R2.2
unnamed: R1.1, U2.7 (!CHRG)
unnamed: R3.2, U2.2 (PROG)
unnamed: IC2.1 (OD), Q3.5 (G2)
unnamed: IC2.3 (OC), Q3.4 (G1)
unnamed: IC2.2 (CS), R12.2
unnamed: C4.1, IC2.5 (VCC), R13.2
VBAT: C5.1, Q4.3 (D), R13.1, R14.2, TP1.TP, U2.5 (BAT), VBAT+.1
VBAT_SENSE: R14.1, R15.2; also elsewhere on the board
VCC: C7.1, D2.C (K), Q4.2 (S), U$2.3 (VIN)
VUSB: D2.A, LED3.A, LED4.A, Q4.1 (G), R16.2, U2.4 (VCC), U2.8 (CE); also elsewhere on the board

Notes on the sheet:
ESP32 + USB Programming
3D PRACTICAL MANUFACTURING
version 1.0

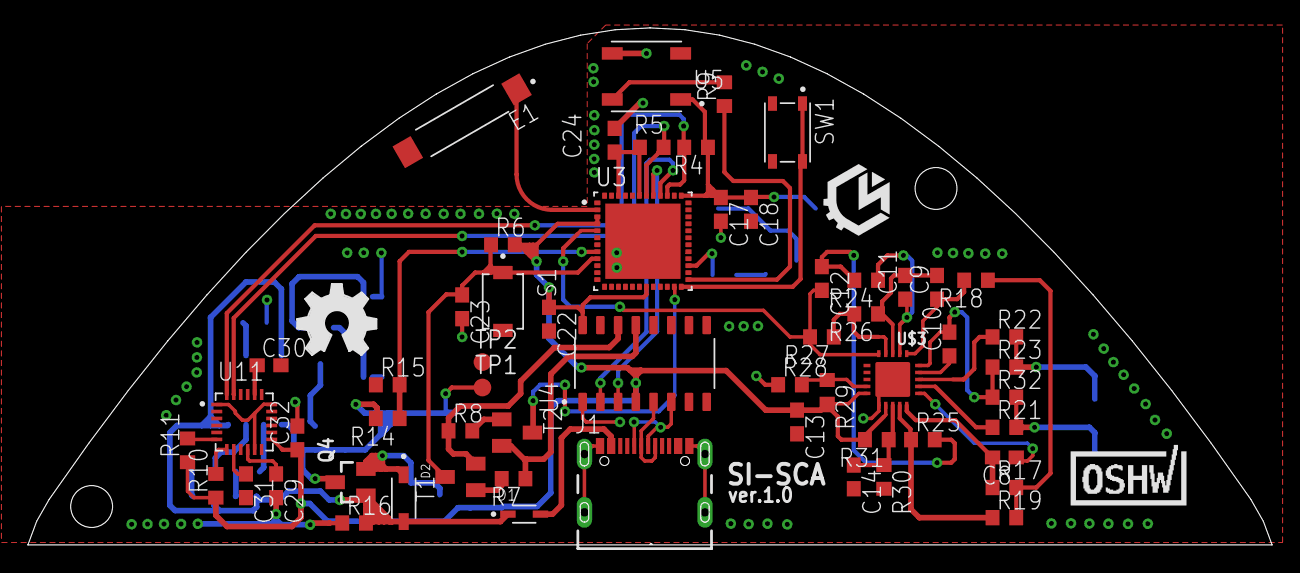
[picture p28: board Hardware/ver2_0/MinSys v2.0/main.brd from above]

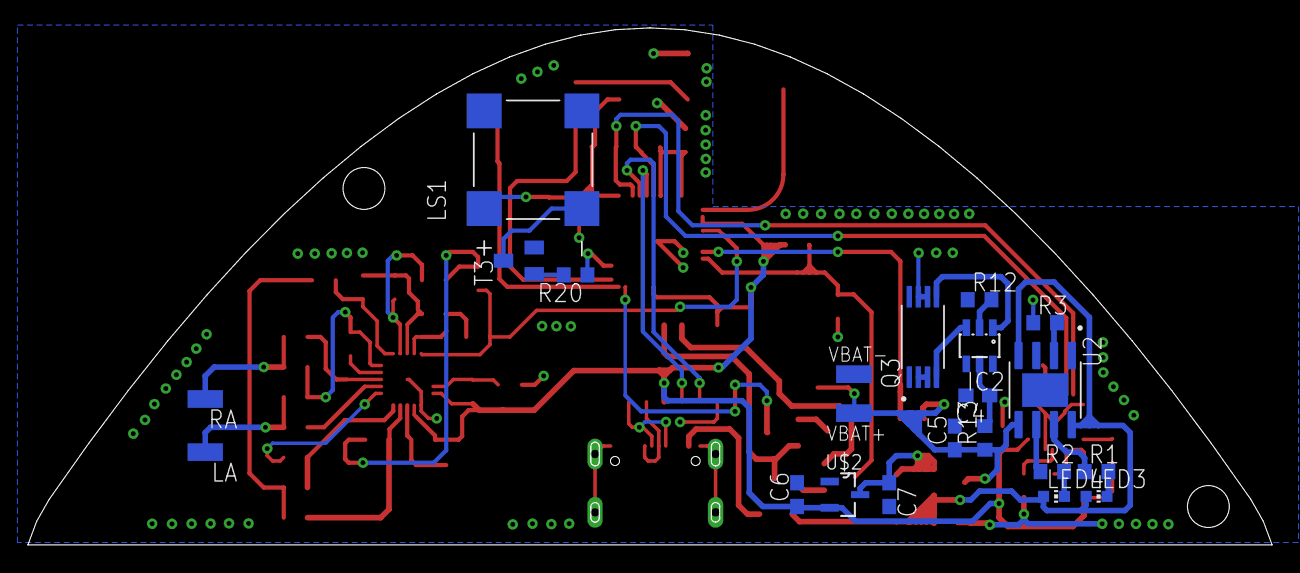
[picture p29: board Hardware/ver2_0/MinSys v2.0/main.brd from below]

Board: 2 copper layers, 89.2 x 37.1 mm, 82 parts (22 on the bottom side), 58 nets.

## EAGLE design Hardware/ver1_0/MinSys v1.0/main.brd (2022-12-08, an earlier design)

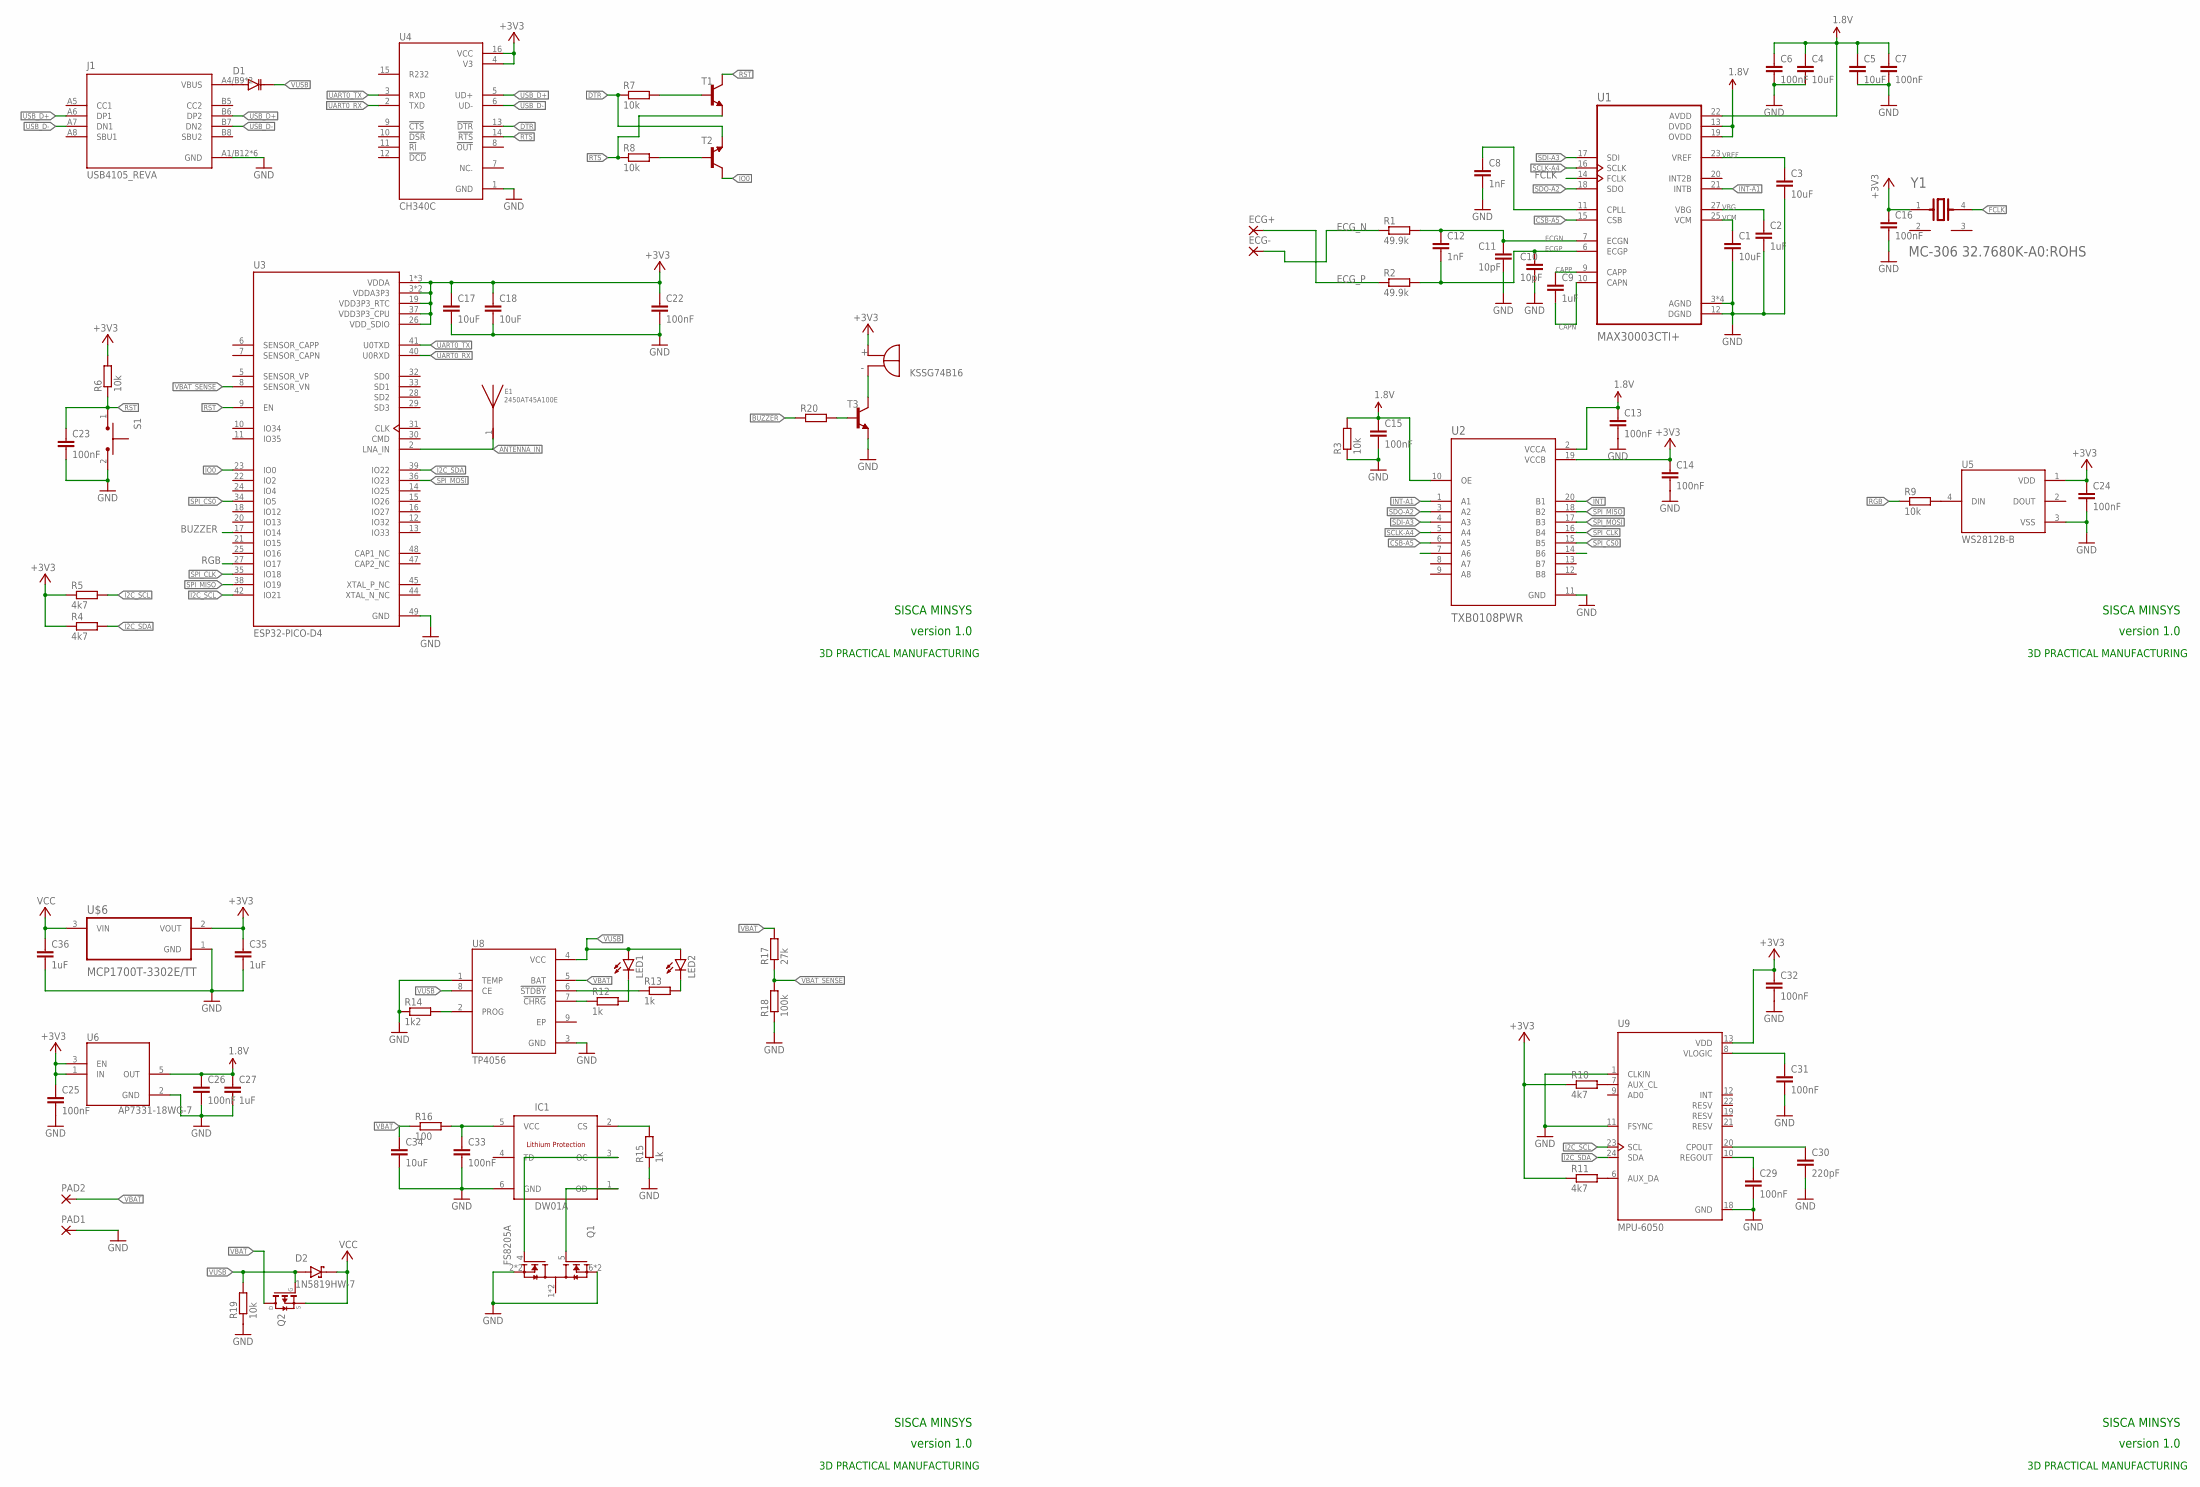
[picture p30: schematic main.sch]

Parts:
C1, C3, C4, C5, C17, C18, C34: 10uF; C0603
C2, C9, C27, C35, C36: 1uF; C0603
C6, C7, C13, C14, C15, C16, C22, C23, C24, C25, C26, C29, C31, C32, C33: 100nF; C0603
C8, C12: 1nF; C0603
C10, C11: 10pF; C0603
C30: 220pF; C0603
D1: ZMV829BTA; SOD2512X116N
D2: 1N5819HW-7; SOD3715X145N
E1: 2450AT45A100E; ANT_2450AT45A100E
ECG+: SMD5; SMD2,54-5,08
ECG-: SMD5; SMD2,54-5,08
IC1: DW01A; SOT23-6
J1: USB4105_REVA; GCT_USB4105_REVA
LED1, LED2: LEDCHIP-LED0603; CHIP-LED0603
LS1: KSSG74B16; XDCR_KSSG74B16
PAD1, PAD2: WIREPADSMD1,27-254; SMD1,27-2,54
Q1: FS8205A; SOP65P640X120-8N
Q2: TRANSISTOR-FET_DMP2004K; TRANSISTOR-FET_SOT23
R1, R2: 49.9k; R0603
R3, R6, R7, R8, R9, R19: 10k; R0603
R4, R5, R10, R11: 4k7; R0603
R12, R13, R15: 1k; R0603
R14: 1k2; R0603
R16: 100; R0603
R17: 27k; R0603
R18: 100k; R0603
R20: R-EU_R0603; R0603
S1: TL1015AF160QG; SW_TL1015AF160QG
T1, T2, T3: MMBT4401LT1-NPN-SOT23-BEC; SOT23-BEC
U1: MAX30003CTI+; QFN50P500X500X80-29N
U2: TXB0108PWR; SOP65P640X120-20N
U3: ESP32-PICO-D4; PQFN50P700X700X104-49N
U4: CH340C; SOIC127P600X180-16N
U5: WS2812B-B; LED_WS2812B-B
U6: AP7331-18WG-7; SOT95P285X145-5N
U8: TP4056; SOP127P600X175-9N
U9: MPU-6050; QFN50P400X400X95-24N
U$6: MCP1700T-3302E/TT; SOT95P237X112-3N
Y1: EPSON_MC-306_32.7680K-A0-ROHSEPSON_MC-306_32.7680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; EPSON_MC-306_32.7680K-A0-ROHS_0

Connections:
1.8V: C4.1, C5.1, C6.1, C7.1, C13.1, C15.1, C26.1, C27.1, R3.2, U1.13 (DVDD), U1.19 (OVDD), U1.22 (AVDD), U2.2 (VCCA), U2.10 (OE), U6.5 (OUT)
+3V3: C14.1, C16.1, C17.1, C18.1, C22.1, C24.1, C25.1, C32.1, C35.1, LS1.P (POS), R4.1, R5.1, R6.2, R10.1, R11.1, U2.19 (VCCB), U3.1 (VDDA), U3.3 (VDDA3P3), U3.4 (VDDA3P3), U3.19 (VDD3P3_RTC), U3.26 (VDD_SDIO), U3.37 (VDD3P3_CPU), U3.43 (VDDA), U3.46 (VDDA), U4.4 (V3), U4.16 (VCC), U5.1 (VDD), U6.1 (IN), U6.3 (EN), U9.13 (VDD), U$6.2 (VOUT), Y1.1
ANTENNA_IN: E1.1, U3.2 (LNA_IN)
BUZZER: R20.1, U3.17 (IO14)
CAPN: C9.2, U1.10 (CAPN)
CAPP: C9.1, U1.9 (CAPP)
CSB-A5: U1.15 (CSB), U2.6 (A5)
DTR: R7.1, T2.E, U4.13 (!DTR)
ECGN: C11.1, C12.1, R1.2, U1.7 (ECGN)
ECGP: C10.1, C12.2, R2.2, U1.6 (ECGP)
ECG_N: ECG-.1, R1.1
ECG_P: ECG+.1, R2.1
FCLK: U1.14 (FCLK), Y1.4
GND: C1.2, C2.2, C3.2, C4.2, C5.2, C6.2, C7.2, C8.2, C10.2, C11.2, C13.2, C14.2, C15.2, C16.2, C17.2, C18.2, C22.2, C23.2, C24.2, C25.2, C26.2, C27.2, C29.2, C30.2, C31.2, C32.2, C33.2, C34.2, C35.2, C36.2, IC1.6 (GND), J1.A1/B12 (GND), J1.B1/A12 (GND), J1.G1 (GND), J1.G2 (GND), J1.G3 (GND), J1.G4 (GND), PAD1.1, Q1.2 (S1), Q1.3 (S1), Q1.6 (S2), Q1.7 (S2), R3.1, R14.1, R15.1, R18.1, R19.1, S1.2, T3.E, U1.3 (AGND), U1.8 (AGND), U1.12 (DGND), U1.28 (AGND), U1.29 (AGND), U2.11 (GND), U3.49 (GND), U4.1 (GND), U5.3 (VSS), U6.2 (GND), U8.1 (TEMP), U8.3 (GND), U9.1 (CLKIN), U9.11 (FSYNC), U9.18 (GND), U$6.1 (GND)
I2C_SCL: R5.2, U3.42 (IO21), U9.23 (SCL)
I2C_SDA: R4.2, U3.39 (IO22), U9.24 (SDA)
INT: U2.20 (B1)
INT-A1: U1.21 (INTB), U2.1 (A1)
IO0: T2.C, U3.23 (IO0)
unnamed: R7.2, T1.B
unnamed: R8.2, T2.B
unnamed: R9.2, U5.4 (DIN)
unnamed: C8.1, U1.11 (CPLL)
unnamed: R20.2, T3.B
unnamed: R10.2, U9.7 (AUX_CL)
unnamed: R11.2, U9.6 (AUX_DA)
unnamed: C29.1, U9.10 (REGOUT)
unnamed: C30.1, U9.20 (CPOUT)
unnamed: R13.1, U8.6 (!STDBY)
unnamed: LED1.C, R12.2
unnamed: LED2.C, R13.2
unnamed: R12.1, U8.7 (!CHRG)
unnamed: R14.2, U8.2 (PROG)
unnamed: IC1.1 (OD), Q1.5 (G2)
unnamed: IC1.3 (OC), Q1.4 (G1)
unnamed: IC1.2 (CS), R15.2
unnamed: C33.1, IC1.5 (VCC), R16.2
unnamed: D1.A, J1.A4/B9 (VBUS), J1.B4/A9 (VBUS)
unnamed: C31.1, U9.8 (VLOGIC)
unnamed: LS1.N (NEG), T3.C
RGB: R9.1, U3.27 (IO17)
RST: C23.1, R6.1, S1.1, T1.C, U3.9 (EN)
RTS: R8.1, T1.E, U4.14 (!RTS)
SCLK-A4: U1.16 (SCLK), U2.5 (A4)
SDI-A3: U1.17 (SDI), U2.4 (A3)
SDO-A2: U1.18 (SDO), U2.3 (A2)
SPI_CLK: U2.16 (B4), U3.35 (IO18)
SPI_CS0: U2.15 (B5), U3.34 (IO5)
SPI_MISO: U2.18 (B2), U3.38 (IO19)
SPI_MOSI: U2.17 (B3), U3.36 (IO23)
UART0_RX: U3.40 (U0RXD), U4.2 (TXD)
UART0_TX: U3.41 (U0TXD), U4.3 (RXD)
USB_D+: J1.A6 (DP1), J1.B6 (DP2), U4.5 (UD+)
USB_D-: J1.A7 (DN1), J1.B7 (DN2), U4.6 (UD-)
VBAT: C34.1, PAD2.1, Q2.3 (D), R16.1, R17.2, U8.5 (BAT)
VBAT_SENSE: R17.1, R18.2, U3.8 (SENSOR_VN)
VBG: C2.1, U1.27 (VBG)
VCC: C36.1, D2.C (K), Q2.2 (S), U$6.3 (VIN)
VCM: C1.1, U1.25 (VCM)
VREF: C3.1, U1.23 (VREF)
VUSB: D1.K, D2.A, LED1.A, LED2.A, Q2.1 (G), R19.2, U8.4 (VCC), U8.8 (CE)

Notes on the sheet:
SISCA MINSYS
3D PRACTICAL MANUFACTURING
version 1.0

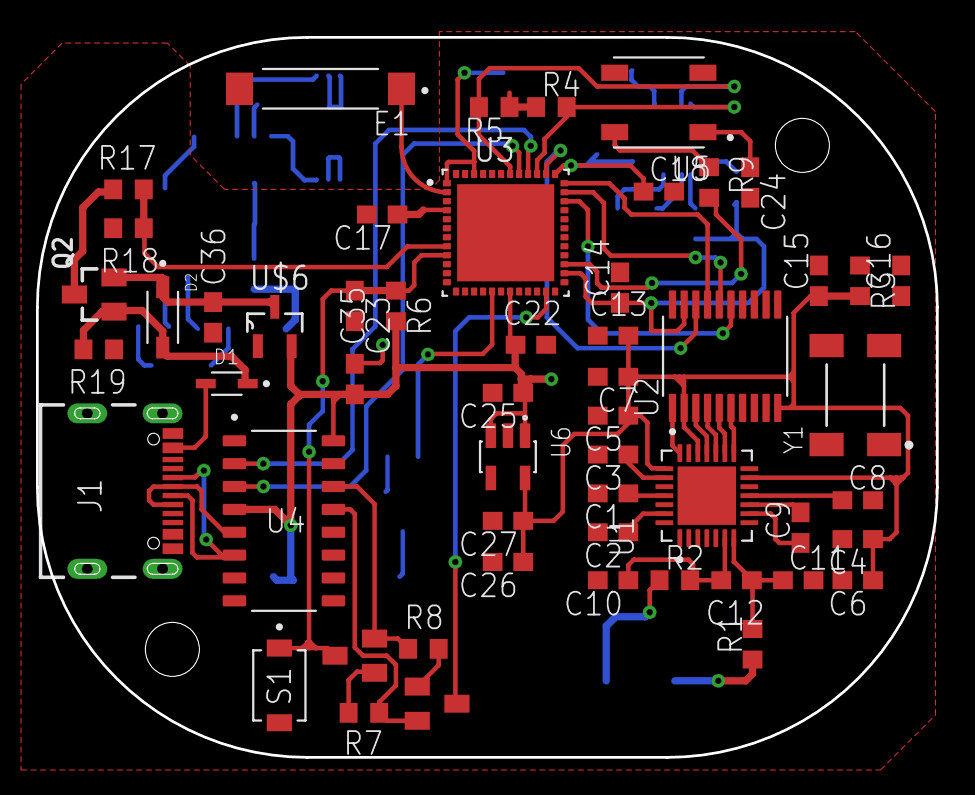
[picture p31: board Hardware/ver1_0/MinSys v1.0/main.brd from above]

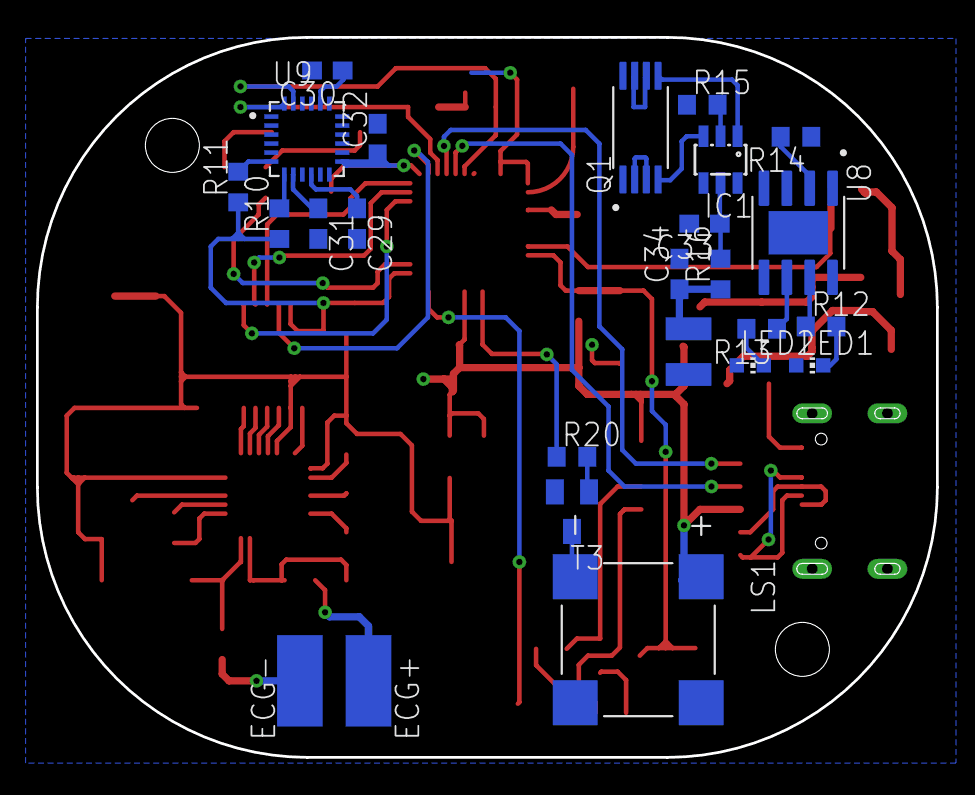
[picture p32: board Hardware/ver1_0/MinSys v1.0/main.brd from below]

Board: 2 copper layers, 50.0 x 40.0 mm, 80 parts (26 on the bottom side), 60 nets.

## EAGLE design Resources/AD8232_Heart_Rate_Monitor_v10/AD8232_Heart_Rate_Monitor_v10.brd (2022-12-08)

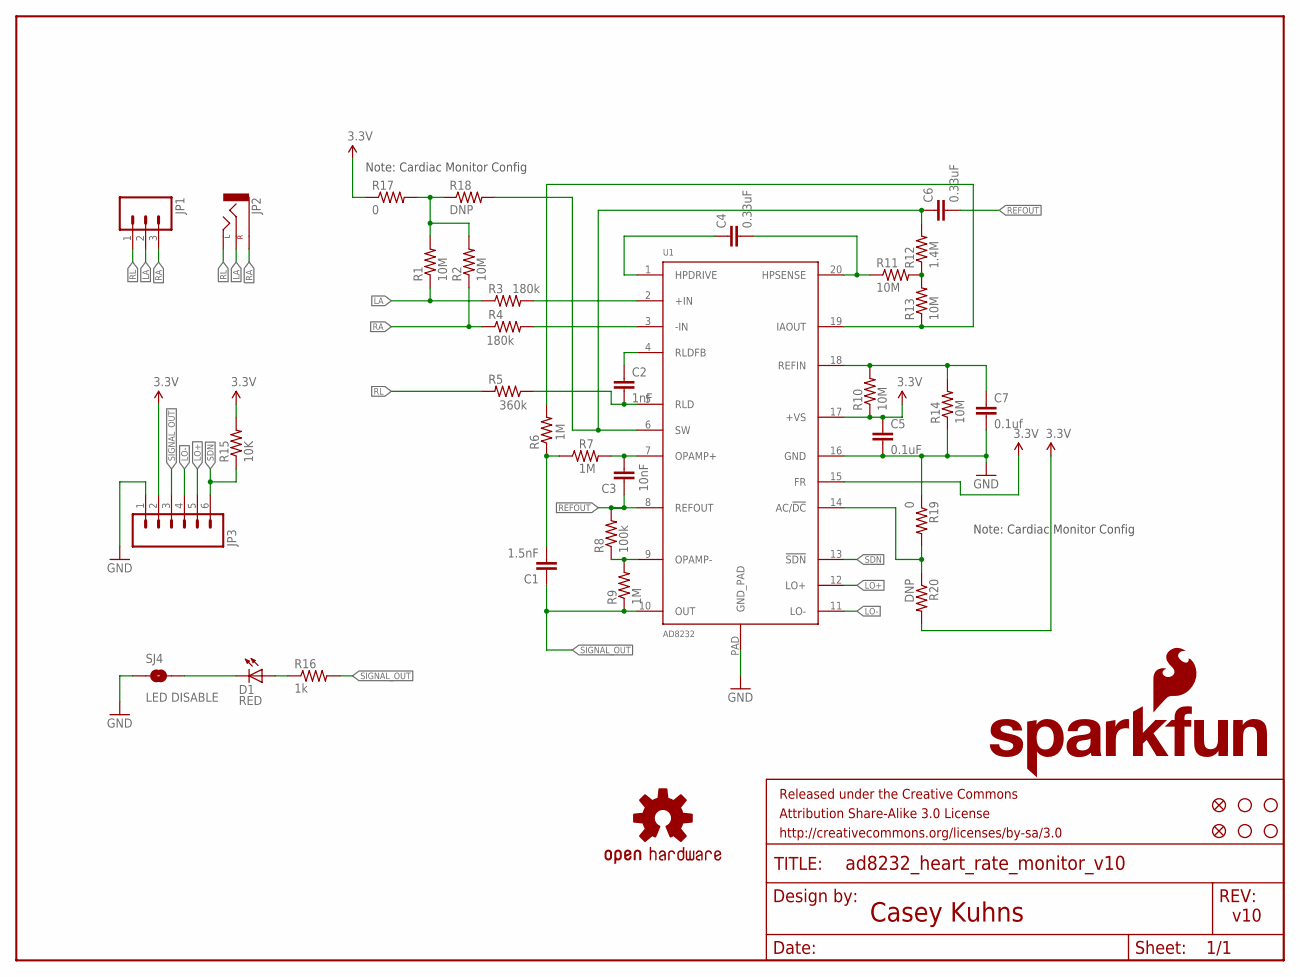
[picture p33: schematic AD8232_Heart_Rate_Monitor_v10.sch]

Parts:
C1: 1.5nF; 0603-CAP
C2: 1nF; 0603-CAP
C3: 10nF; 0603-CAP
C4, C6: 0.33uF; 0805
C5: 0.1uF; 0603-CAP
C7: 0.1uf; 0603-CAP
D1: RED; LED-0603
FID1, FID2: FIDUCIAL1X2; FIDUCIAL-1X2
FRAME1: FRAME-LETTER; CREATIVE_COMMONS
JP1: M03PTH; 1X03
JP2: AUDIO-JACKSMD2; AUDIO-JACK-3.5MM-SMD
JP3: M06SIP; 1X06
LOGO1: OSHW-LOGOS; OSHW-LOGO-S
LOGO2: SFE_LOGO_NAME_FLAME.1_INCH; SFE_LOGO_NAME_FLAME_.1
R1, R2, R10, R11, R13, R14: 10M; 0603-RES
R3, R4: 180k; 0603-RES
R5: 360k; 0603-RES
R6, R7, R9: 1M; 0603-RES
R8: 100k; 0603-RES
R12: 1.4M; 0603-RES
R15: 10K; 0603-RES
R16: 1k; 0603-RES
R17, R19: 0; 0603
R18, R20: DNP; 0603
SJ4: LED DISABLE; SJ_2S-TRACE
STANDOFF1, STANDOFF2, STANDOFF3, STANDOFF4: STAND-OFF
U1: AD8232; LFCSP_20

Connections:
3.3V: C5.1, JP3.2, R10.1, R15.2, R17.1, R20.2, U1.15 (FR), U1.17 (+VS)
GND: C5.2, C7.2, JP3.1, R14.1, R19.1, SJ4.1, U1.16 (GND), U1.PAD (GND_PAD)
LA: JP1.2, JP2.RING (RIGHT), R1.1, R3.1
LO+: JP3.5, U1.12 (LO+)
LO-: JP3.4, U1.11 (LO-)
unnamed: R3.2, U1.2 (+IN)
unnamed: R4.2, U1.3 (-IN)
unnamed: C3.2, R7.2, U1.7 (OPAMP+)
unnamed: C4.2, R11.1, U1.20 (HPSENSE)
unnamed: C7.1, R10.2, R14.2, U1.18 (REFIN)
unnamed: D1.A, R16.1
unnamed: R8.1, R9.2, U1.9 (OPAMP-)
unnamed: R6.2, R13.1, U1.19 (IAOUT)
unnamed: C1.2, R6.1, R7.1
unnamed: D1.C, SJ4.2
unnamed: R19.2, R20.1, U1.14 (AC/!DC)
unnamed: C4.1, U1.1 (HPDRIVE)
unnamed: R11.2, R12.1, R13.2
unnamed: C6.1, R12.2, R18.2, U1.6 (SW)
unnamed: C2.1, U1.4 (RLDFB)
unnamed: C2.2, R5.1, U1.5 (RLD)
unnamed: R1.2, R2.2, R17.2, R18.1
RA: JP1.3, JP2.SLEEVE, R2.1, R4.1
REFOUT: C3.1, C6.2, R8.2, U1.8 (REFOUT)
RL: JP1.1, JP2.TIP (LEFT), R5.2
SDN: JP3.6, R15.1, U1.13 (!SDN)
SIGNAL_OUT: C1.1, JP3.3, R9.1, R16.2, U1.10 (OUT)

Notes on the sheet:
Casey Kuhns
v10
Note: Cardiac Monitor Config

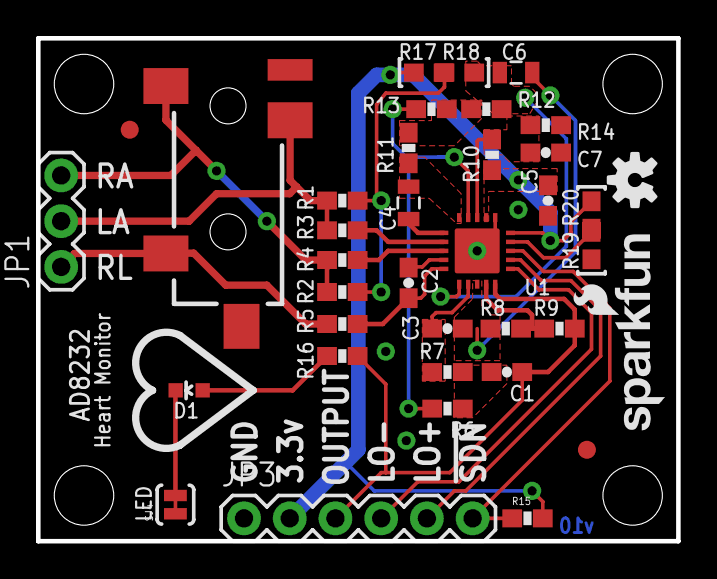
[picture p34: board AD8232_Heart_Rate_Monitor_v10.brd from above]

Board: 2 copper layers, 35.6 x 27.9 mm, 42 parts (0 on the bottom side), 27 nets.

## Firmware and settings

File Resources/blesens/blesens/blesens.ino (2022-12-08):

#include <BLEDevice.h>
#include <BLEServer.h>
#include <BLEUtils.h>
#include <BLE2902.h>

BLEServer* pServer = NULL;
BLECharacteristic* HRMonCharacteristic = NULL;
BLECharacteristic* BattMonCharacteristic = NULL;
BLECharacteristic* ECGCharacteristic = NULL;
BLECharacteristic* CondCharacteristic = NULL;

bool deviceConnected = false;
bool oldDeviceConnected = false;
uint32_t value = 0;

unsigned long lastScan;
unsigned long lastTrans;

int adc;

// See the following for generating UUIDs:
// https://www.uuidgenerator.net/

// #define HR_SERVICE_UUID        "0000180d-0000-1000-8000-00805f9b34fb"
// #define HR_CHARACTERISTIC_UUID "00002a37-0000-1000-8000-00805f9b34fb"

static BLEUUID HR_SERVICE_UUID(BLEUUID((uint16_t)0x180D));
static BLEUUID HR_CHARACTERISTIC_UUID(BLEUUID((uint16_t)0x2A37));

// #define BATT_UUID              "0000180f-0000-1000-8000-00805f9b34fb"
// #define BATT_C_UUID            "00002a19-0000-1000-8000-00805f9b34fb"

static BLEUUID BATT_UUID(BLEUUID((uint16_t)0x180F));
static BLEUUID BATT_C_UUID(BLEUUID((uint16_t)0x2A19));

// #define BATT_UUID              "0000183e-0000-1000-8000-00805f9b34fb"
// #define BATT_C_UUID            "00002a58-0000-1000-8000-00805f9b34fb"

static BLEUUID ECG_UUID(BLEUUID((uint16_t)0x183E));
static BLEUUID ECG_C_UUID(BLEUUID((uint16_t)0x2A58));

// #define BATT_UUID              "0000181a-0000-1000-8000-00805f9b34fb"
// #define BATT_C_UUID            "0000290c-0000-1000-8000-00805f9b34fb"

static BLEUUID COND_UUID(BLEUUID((uint16_t)0x181A));
static BLEUUID COND_C_UUID(BLEUUID((uint16_t)0x290C));

class MyServerCallbacks: public BLEServerCallbacks {
    void onConnect(BLEServer* pServer) {
      deviceConnected = true;
    }

    void onDisconnect(BLEServer* pServer) {
      deviceConnected = false;
    }
};

void sendTask(void *pvParameters)
{
  while(1){
    if (deviceConnected) {
        int adc = random(55, 75);
        String x = String(adc);
        HRMonCharacteristic->setValue(x.c_str());
        HRMonCharacteristic->notify();
        vTaskDelay(750);
    }
    // disconnecting
    if (!deviceConnected && oldDeviceConnected) {
        pServer->startAdvertising(); // restart advertising
        // Serial.println("start advertising");
        oldDeviceConnected = deviceConnected;
    }
    // connecting
    if (deviceConnected && !oldDeviceConnected) {
        // do stuff here on connecting
        oldDeviceConnected = deviceConnected;
    }
  }
}

void sendTask2(void *pvParameters)
{
  while(1){
    if (deviceConnected) {
        int x = random(1,99);
        String aa = String(x);
        BattMonCharacteristic->setValue(aa.c_str());
        BattMonCharacteristic->notify();
        digitalWrite(2, x%2);
        vTaskDelay(1000);
    }
    // disconnecting
    if (!deviceConnected && oldDeviceConnected) {
        pServer->startAdvertising(); // restart advertising
        // Serial.println("start advertising");
        oldDeviceConnected = deviceConnected;
    }
    // connecting
    if (deviceConnected && !oldDeviceConnected) {
        // do stuff here on connecting
        oldDeviceConnected = deviceConnected;
    }
  }
}
void sendTask3(void *pvParameters)
{
  while(1){
    if (deviceConnected) {
        int x = random(1,4095);
        ECGCharacteristic->setValue(x);
        ECGCharacteristic->notify();
        digitalWrite(2, x%2);
        vTaskDelay(10);
    }
    // disconnecting
    if (!deviceConnected && oldDeviceConnected) {
        pServer->startAdvertising(); // restart advertising
        // Serial.println("start advertising");
        oldDeviceConnected = deviceConnected;
    }
    // connecting
    if (deviceConnected && !oldDeviceConnected) {
        // do stuff here on connecting
        oldDeviceConnected = deviceConnected;
    }
  }
}

void sendTask4(void *pvParameters)
{
  while(1){
    if (deviceConnected) {
        String condition[3] = {"FALL", "SLEEP", "STAND"};
        int x = random(0,2);
        String aa = condition[x];
        CondCharacteristic->setValue(aa.c_str());
        CondCharacteristic->notify();
        digitalWrite(2, x%2);
        vTaskDelay(5000);
    }
    // disconnecting
    if (!deviceConnected && oldDeviceConnected) {
        pServer->startAdvertising(); // restart advertising
        // Serial.println("start advertising");
        oldDeviceConnected = deviceConnected;
    }
    // connecting
    if (deviceConnected && !oldDeviceConnected) {
        // do stuff here on connecting
        oldDeviceConnected = deviceConnected;
    }
  }
}

void setup() {
  Serial.begin(115200);
  pinMode(2, OUTPUT);
  // Create the BLE Device
  BLEDevice::init("Si-SCA");

  // Create the BLE Server
  pServer = BLEDevice::createServer();
  pServer->setCallbacks(new MyServerCallbacks());

  // Create the BLE Service
  BLEService *HRMonService = pServer->createService(HR_SERVICE_UUID);

  // Create a BLE Characteristic
  HRMonCharacteristic = HRMonService->createCharacteristic(
                      HR_CHARACTERISTIC_UUID,
                      BLECharacteristic::PROPERTY_READ   |
                      BLECharacteristic::PROPERTY_WRITE  |
                      BLECharacteristic::PROPERTY_NOTIFY |
                      BLECharacteristic::PROPERTY_INDICATE
                    );
  HRMonCharacteristic->addDescriptor(new BLE2902());

  BLEService *BattMonService = pServer->createService(BATT_UUID);

  BattMonCharacteristic = BattMonService->createCharacteristic(
                      BATT_C_UUID,
                      BLECharacteristic::PROPERTY_READ   |
                      BLECharacteristic::PROPERTY_WRITE  |
                      BLECharacteristic::PROPERTY_NOTIFY |
                      BLECharacteristic::PROPERTY_INDICATE
                    );
  BattMonCharacteristic->addDescriptor(new BLE2902());

  BLEService *CondService = pServer->createService(COND_UUID);

  CondCharacteristic = CondService->createCharacteristic(
                      COND_C_UUID,
                      BLECharacteristic::PROPERTY_READ   |
                      BLECharacteristic::PROPERTY_WRITE  |
                      BLECharacteristic::PROPERTY_NOTIFY |
                      BLECharacteristic::PROPERTY_INDICATE
                    );
  CondCharacteristic->addDescriptor(new BLE2902());

  BLEService *ECGService = pServer->createService(ECG_UUID);

  ECGCharacteristic = ECGService->createCharacteristic(
                      ECG_C_UUID,
                      BLECharacteristic::PROPERTY_READ   |
                      BLECharacteristic::PROPERTY_WRITE  |
                      BLECharacteristic::PROPERTY_NOTIFY |
                      BLECharacteristic::PROPERTY_INDICATE
                    );
  ECGCharacteristic->addDescriptor(new BLE2902());
  
  // Start the service
  HRMonService->start();
  BattMonService->start();
  ECGService->start();
  CondService->start();

  // Start advertising
  BLEAdvertising *pAdvertising = BLEDevice::getAdvertising();
  pAdvertising->addServiceUUID(HR_SERVICE_UUID);
  pAdvertising->setScanResponse(false);
  pAdvertising->setMinPreferred(0x0);  // set value to 0x00 to not advertise this parameter
  BLEDevice::startAdvertising();
  Serial.println("Waiting a client connection to notify...");

  xTaskCreate(sendTask, "Send HR", 2048, NULL, 1, NULL);
  xTaskCreate(sendTask2, "Send Batt", 2048, NULL, 1, NULL);
  xTaskCreate(sendTask3, "Send ECG", 2048, NULL, 1, NULL);
  xTaskCreate(sendTask4, "Send Condition", 2048, NULL, 1, NULL);
}

void loop() {}

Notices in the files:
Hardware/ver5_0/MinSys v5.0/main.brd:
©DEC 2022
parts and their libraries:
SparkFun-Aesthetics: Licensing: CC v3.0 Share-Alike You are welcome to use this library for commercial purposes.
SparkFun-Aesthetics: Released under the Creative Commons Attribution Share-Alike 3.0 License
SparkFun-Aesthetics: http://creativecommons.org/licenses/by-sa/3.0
